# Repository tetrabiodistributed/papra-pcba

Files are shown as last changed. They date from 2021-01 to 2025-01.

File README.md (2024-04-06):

# PAPRA Printed Circuit Board Assembly (PCBA)

Full documentation page for building the PAPRa can be found here: https://tetrabiodistributed.github.io/papra/

Firmware for flashing the PAPRA PCBA can be found here: https://github.com/tetrabiodistributed/papra-pcb-firmware/tree/main/papracode

## Notes for programming

* Make a UPDI Programmer: https://create.arduino.cc/projecthub/john-bradnam/create-your-own-updi-programmer-1e55f1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
* The board features a UPDI header on the top left of the PCB (top being the side with the battery connectors) the pins are top to bottom 5V, GND and data. 
* Setup Arduino: https://www.hackster.io/john-bradnam/using-the-new-attiny-processors-with-arduino-ide-612185
* You will need to use the megaTinyCore library by SpenceKonde: https://github.com/SpenceKonde/megaTinyCore

Upload settings can be found in the arduino program. 

Please note that there are a number of ATTiny SKUs that are compatible with this PCB and code, please refer to the below table when choosing an appropriate IC.

| Model number | Confirmed | Notes |
| --- | --- | --- |
| ATtiny204SSN_, | Yes | See Below(1)  |
| ATtiny404SSN_, | Yes | 	 |
| ATtiny804SSN_, | Yes | |
| ATtiny1604SSN_,| Yes | 	 |
| ATtiny214SSN_, | Yes | See Below(1)  |
| ATtiny414SSN_, | Yes | 	 |
| ATtiny814SSN_, | Yes | |
| ATtiny1614SSN_,| Yes | 	 |
| ATtiny1624SSU, | Yes | 	 |

(1)ATtiny 204 and 214 have limited (2K) flash memory for program space, but the firmware can be made to fit by sacraficing the bootup LED sequence.

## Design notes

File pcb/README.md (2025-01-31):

The Tetra PAPRA project requires 1 PCBA, v.7 or newer.

PaprControlPCB - this is a speed controller that allows for adjusting speed of blower

Note:
A PCB is a bare board.
A PCBA is an assembly of a PCB and OTS (off the shelf) components, which are typically a mix of surface mount and thru-hole components.

PCBA Bring-Up Instructions:

1. Connect power to the board via 2.5mm DC jack (H1) using 12V Nominal (7V min, 14V max) DC power, ideally current limitable. Do not connect fan to the output connector at this time.



* Note DC polarity on connector is important, center pin is positive.
   * Insertion length on connector is 8.4mm, so body of mating jack should be at least this length.
   * For use with a bench power supply, a cut-end cable option is [Tensility CA-2185](https://www.digikey.com/en/products/detail/tensility-international-corp/CA-2185/568576) 
   * For a standalone power adapter, consider a [Tri-Mag L6R06H-120 12V/6W supply](https://www.digikey.com/en/products/detail/tri-mag-llc/L6R06H-120/7682617)
2. For adjustable power supply, set the voltage to12V and set initial current limit to ~25mA, which should be sufficient to power up processor and drive LEDs.
3. Turn the potentiometer/switch (POT1) to ON. 



4. Confirm the power LED (LED5) illuminates with 12V power.



5. Measure 5V regulator (U1) is outputting 5VDC. This can be inspected with a voltmeter measuring the UDPI header as follows:
   * Pin 2 is GND
   * Pin 3 is +5V
6. At this point, the board is powered and ready for programming via UPDI. Follow the instructions [here.](https://github.com/tetrabiodistributed/PAPRA-PCB/blob/main/README.md).
7. Upon successful completion of firmware installation, confirm the board powers up and the 4 LEDs (LED1 - LED4) light up at boot up in a sequence.
8. For boards with the buzzer installed, confirm the buzzer chirps at bootup.
9. In preparation for testing with a DC blower and battery, disconnect the DC jack from H1.
10. Source a fully charged [Milwaukee M12 Red Lithium Battery 48-11-2401](https://www.milwaukeetool.com/Products/Batteries-and-Chargers/M12-Batteries-and-Chargers/48-11-2401) or similar. 
11. Connect DC power to BNC connector (H2).
* WARNING: If the board is not installed in the battery housing, pay careful attention to the polarity
12. Turn on potentiometer (POT1) and adjust the fan speed from high to low, which checking the DC blower is working and speed is changing with potentiometer adjustments.

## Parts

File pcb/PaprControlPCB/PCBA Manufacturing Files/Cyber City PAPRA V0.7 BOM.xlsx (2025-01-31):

 | Client Name | Patrick Campbell |  |  | The better this is filled out, the easier our job is and we appreciate the help.
 | Company Name | Tetra Bio Distributed
 | Phone Number
 | Email Address | patrick.campbell@tetrab.io |  |  | Please complete Columns B, C, D, E, F and G. Additional notes always help us do a better job.
 | Board Name | PAPRA V0.7
 | Assembly Quantity | 25
Line | Description | Designators | Package | Qty | Manufacturer | MPN | Notes | Substitute | Customer Provided? | Vendor | Vendor PN | Vendor PPU
1 | Solder Tab Terminal; Uninsulated; Tin over Nickel Plated; Right Angle; 6.35x0.83mm | BATT+ BATT- | THT | 2 | TE Connectivity | 1217754-1 |  |  |  | DigiKey | A112005-ND | 0.2314 | 2 | TE Connectivity | 1217754-1
2 | Multilayer Ceramic Capacitor, 1 uF, 50 V, Â± 10%, X7R, 0805 [2012 Metric] | C1 C3 C8 C11 | C0805 | 4 | Samsung | CL21B105KBFNNNG |  |  |  | DigiKey | 1276-6470-1-ND | 0.0373 | 4 | Samsung | CL21B105KBFNNNG
3 | Multilayer Ceramic Capacitor, 0.1 uF, 50 V, Â± 10%, X7R, 0805 [2012 Metric] | C2 C9 C10 | C0805 | 3 | Samsung | CL21B104KBCNFNC |  |  |  | DigiKey | 1276-2444-1-ND | 0.0206 | 3 | Samsung | CL21B104KBCNFNC
4 | Cap Tant Solid 10uF 16V A CASE 10%( 3.2 X 1.6 X 1.6mm) Inward L SMD 3216-18 3 Ohm 125C T/R | C4 | A/3216-18R | 1 | KYOCERA AVX | TAJA106K016RNJ |  |  |  | DigiKey | 478-1655-1-ND | 0.1878 | 1 | KYOCERA AVX | TAJA106K016RNJ
5 | Multilayer Ceramic Capacitor, 3600 pF, 50 V, Â± 5%, C0G (NP0), 0805 [2012 Metric] | C5 | C0805 | 1 | Murata | GRM2165C1H362JA01D |  |  |  | DigiKey | 490-3318-1-ND | 0.069 | 1 | Murata | GRM2165C1H362JA01D
6 | Multilayer Ceramic Capacitor, 2700 pF, 50 V, Â± 5%, C0G (NP0), 0805 [2012 Metric] | C6 | C0805 | 1 | TDK | C2012C0G1H272J060AA |  |  |  | DigiKey | 445-7508-1-ND | 0.0768 | 1 | TDK | C2012C0G1H272J060AA
7 | Multilayer Ceramic Capacitor, 10 uF, 16 V, Â± 10%, X5R, 0805 [2012 Metric] | C7 | C0805 | 1 | Samsung | CL21A106KOQNNNG |  |  |  | DigiKey | 1276-6455-1-ND | 0.0404 | 1 | Samsung | CL21A106KOQNNNG
8 | ALU Electrolytic; SMD; EDT; +125Â°C; 25VDC; 10ÂµF; 10 x 10.2 | C12 | PANASONIC_F | 1 | KEMET | EDT227M025S9PAA |  |  |  | DigiKey | 399-20523-1-ND | 0.5946 | 1 | KEMET | EDT227M025S9PAA
9 | Diode Schottky Barrier 100V 1A 2-Pin SOD-123FL T/R | D1 D2 | SODFL3718X115 | 2 | ROHM | RB168MM100TR |  |  |  | DigiKey | RB168MM100CT-ND | 0.2274 | 2 | ROHM | RB168MM100TR
10 | 2.0 x 5.7 mm, 5.0 A, Horizontal, Panel Mount, Dc Power Jack Connector | H1 | THT | 1 | CUI Devices | PJ-066A |  |  |  | DigiKey | CP-066A-ND | 2.3224 | 1 | CUI Devices | PJ-066A
11 | Conn BNC RCP 0Hz to 4GHz 50Ohm Solder RA Thru-Hole Gold Tube | H2 | THT | 1 | TE Connectivity | 5226990-3 |  |  |  | DigiKey | A32254-ND | 3.5854 | 1 | TE Connectivity | 5226990-3
12 | 2.0X1.2MM Red SMD 0805 Led | LED1 LED2 LED3 LED4 LED5 | CHIPLED_0805 | 5 | SunLED | XZMDK54W-4 |  |  |  | DigiKey | 1497-XZMDK54W-4CT-ND | 0.1118 | 5 | SunLED | XZMDK54W-4
13 | Res Conductive Plastic POT 10K Ohm 20% 1/20W 1(Mech)Turn 6mm Pin Panel Mount/Through Hole | POT1 | THT | 1 | BI Technologies | P091S-FC20BR10K |  |  |  | DigiKey | 987-1283-ND | 1.818 | 1 | BI Technologies | P091S-FC20BR10K
14 | N-Channel 20 V 90 mOhm Surface Mount Enhancement Mode Mosfet -SOT-23-3 | Q1 Q2 | SOT23 | 2 | Diodes Inc. | DMG2302U-7 |  |  |  | DigiKey | DMG2302U-7DICT-ND | 0.2117 | 2 | Diodes Inc. | DMG2302U-7
15 | Res Thick Film 0805 10K Ohm 1% 0.125W Â±100ppm/Â°C Molded SMD Paper T/R | R1 R9 R11 R12 R20 | R0805 | 5 | Stackpole Electronics | RMCF0805FT10K0 |  |  |  | DigiKey | RMCF0805FT10K0CT-ND | 0.0102 | 5 | Stackpole Electronics | RMCF0805FT10K0
16 | Res Thick Film 0805 18K Ohm 1% 1/8W Â±100ppm/Â°C Molded SMD SMD Paper T/R | R2 | R0805 | 1 | Stackpole Electronics | RMCF0805FT18K0 |  |  |  | DigiKey | RMCF0805FT18K0CT-ND | 0.025 | 1 | Stackpole Electronics | RMCF0805FT18K0
17 | Res Thick Film 0805 120 Ohm 1% 1/8W Â±100ppm/Â°C Molded SMD SMD Paper T/R | R4 R5 R6 R7 R8 R13 | R0805 | 6 | Yageo | RC0805FR-13120RL |  |  |  | DigiKey | 13-RC0805FR-13120RLCT-ND | 0.0133 | 6 | Yageo | RC0805FR-13120RL
18 | Res Thick Film 0805 1.2K Ohm 1% 0.125W Â±100ppm/Â°C Molded SMD Paper T/R | R10 | R0805 | 1 | Stackpole Electronics | RMCF0805FT1K20 |  |  |  | DigiKey | RMCF0805FT1K20CT-ND | 0.025 | 1 | Stackpole Electronics | RMCF0805FT1K20
19 | Res Thick Film 0805 470K Ohm 1% 0.125W(1/8W) +/-100ppm/ÃŸC Epoxy SMD T/R | R14 | R0805 | 1 | Yageo | RC0805FR-07470KL |  |  |  | DigiKey | 311-470KCRCT-ND | 0.0340 | 1 | Yageo | RC0805FR-07470KL
20 | Res Thick Film 0805 75K Ohm 1% 0.125W Â±100ppm/Â°C Molded SMD Paper T/R | R15 | R0805 | 1 | Stackpole Electronics | RMCF0805FT75K0 |  |  |  | DigiKey | RMCF0805FT75K0CT-ND | 0.025 | 1 | Stackpole Electronics | RMCF0805FT75K0
21 | Res Thick Film 0805 390K Ohm 1% 1/8W Â±100ppm/Â°C Molded SMD SMD Paper T/R | R16 | R0805 | 1 | Stackpole Electronics | RMCF0805FT390K |  |  |  | DigiKey | RMCF0805FT390KCT-ND | 0.025 | 1 | Stackpole Electronics | RMCF0805FT390K
22 | Res Thick Film 0805 1K Ohm 1% 0.125W(1/8W) Â±100ppm/C Pad SMD Automotive T/R | R17 | R0805 | 1 | Stackpole Electronics | RMCF0805FT1K00 |  |  |  | DigiKey | RMCF0805FT1K00CT-ND | 0.025 | 1 | Stackpole Electronics | RMCF0805FT1K00
23 | Res Thick Film 0805 360K Ohm 1% 1/8W Â±100ppm/Â°C Molded SMD SMD Paper T/R | R18 | R0805 | 1 | Stackpole Electronics | RMCF0805FT360K |  |  |  | DigiKey | RMCF0805FT360KCT-ND | 0.025 | 1 | Stackpole Electronics | RMCF0805FT360K
24 | Res Thick Film 0805 56K Ohm 1% 1/8W Â±100ppm/Â°C Molded SMD SMD Paper T/R | R19 | R0805 | 1 | Stackpole Electronics | RMCF0805FT56K0 |  |  |  | DigiKey | RMCF0805FT56K0CT-ND | 0.025 | 1 | Stackpole Electronics | RMCF0805FT56K0
25 | 12 mm, 12 Vdc, 85 dB, Through Hole, Driving Circuit, Magnetic Audio Indicator Buzzer | SG1 | F/TMB | 1 | CUI Devices | CMI-1295-1285T |  |  |  | DigiKey | 102-CMI-1295-1285T-ND | 0.858 | 1 | CUI Devices | CMI-1295-1285T
26 | 150-mA 16-V low-dropout (LDO) voltage regulator with high-accuracy 5-SOT-23 -40 to 125 | U1 | SOT25 | 1 | Texas Instruments | LP2985A-50DBVR |  |  |  | DigiKey | 296-26128-1-ND | 0.538 | 1 | Texas Instruments | LP2985A-50DBVR
27 | AVR series Microcontroller IC 8-Bit 20MHz 16KB (16K x 8) FLASH 14-SOIC | U2 | SOIC14 | 1 | Microchip | ATTINY1624-SSU |  |  |  | DigiKey | 150-ATTINY1624-SSU-ND | 0.9316 | 1 | Microchip | ATTINY1624-SSU
28 | 2.7-V to 23-V, 28-mâ„¦, 5.5-A eFuse with integrated reverse polarity protection 10-VQFN-HR -40 to 125 | U9 | 10-VQFN-HR | 1 | Texas Instruments | TPS259472ARPWR |  |  |  | DigiKey | 296-TPS259472ARPWRCT-ND | 1.3356 | 1 | Texas Instruments | TPS259472ARPWR
29 |  |  | N/A |  |  |  |  |  |  |  |  |  | 1 | Dialight | 515-1020F
30 |  |  | N/A
31 |  |  | N/A
32 |  |  | N/A
33 |  |  | N/A
34 |  |  | N/A
35 |  |  | N/A
36 |  |  | N/A
37 |  |  | N/A
38 |  |  | N/A
39 |  |  | N/A
40 |  |  | N/A
41 |  |  | N/A
42 |  |  | N/A
43 |  |  | N/A
44 |  |  | N/A
45 |  |  | N/A
46 |  |  | N/A
47 |  |  | N/A
48 |  |  | N/A
49 |  |  | N/A
50 |  |  | N/A
51 |  |  | N/A
52 |  |  | N/A
53 |  |  | N/A
54 |  |  | N/A
55 |  |  | N/A
56 |  |  | N/A
57 |  |  | N/A
58 |  |  | N/A
59 |  |  | N/A
60 |  |  | N/A
61 |  |  | N/A
62 |  |  | N/A
63 |  |  | N/A
64 |  |  | N/A
65 |  |  | N/A
66 |  |  | N/A
67 |  |  | N/A
68 |  |  | N/A
69 |  |  | N/A
70 |  |  | N/A
71 |  |  | N/A
72 |  |  | N/A
73 |  |  | N/A
74 |  |  | N/A
75 |  |  | N/A
76 |  |  | N/A
77 |  |  | N/A
78 |  |  | N/A
79 |  |  | N/A
80 |  |  | N/A
81 |  |  | N/A
82 |  |  | N/A
83 |  |  | N/A
84 |  |  | N/A
85 |  |  | N/A
86 |  |  | N/A
87 |  |  | N/A
88 |  |  | N/A
89 |  |  | N/A
90 |  |  | N/A
91 |  |  | N/A
92 |  |  | N/A
93 |  |  | N/A
94 |  |  | N/A
95 |  |  | N/A
96 |  |  | N/A
97 |  |  | N/A
98 |  |  | N/A
99 |  |  | N/A
100 |  |  | N/A

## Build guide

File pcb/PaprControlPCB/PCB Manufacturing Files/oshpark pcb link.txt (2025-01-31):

https://oshpark.com/shared_projects/L2hfni0D

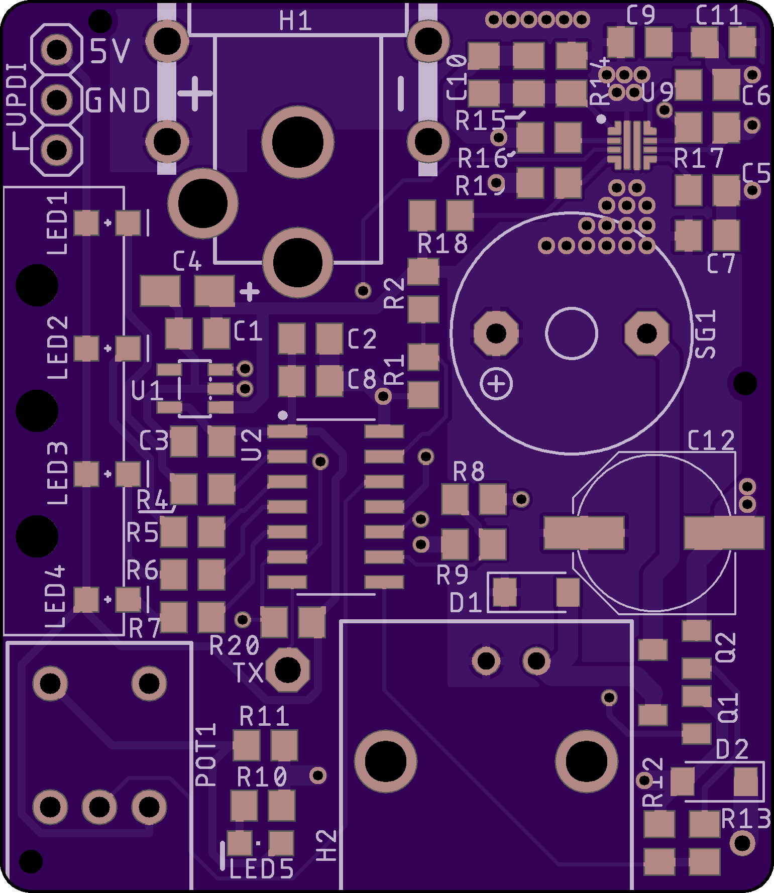
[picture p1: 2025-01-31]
pcb/PaprControlPCB/PCB Manufacturing Files/top.PNG

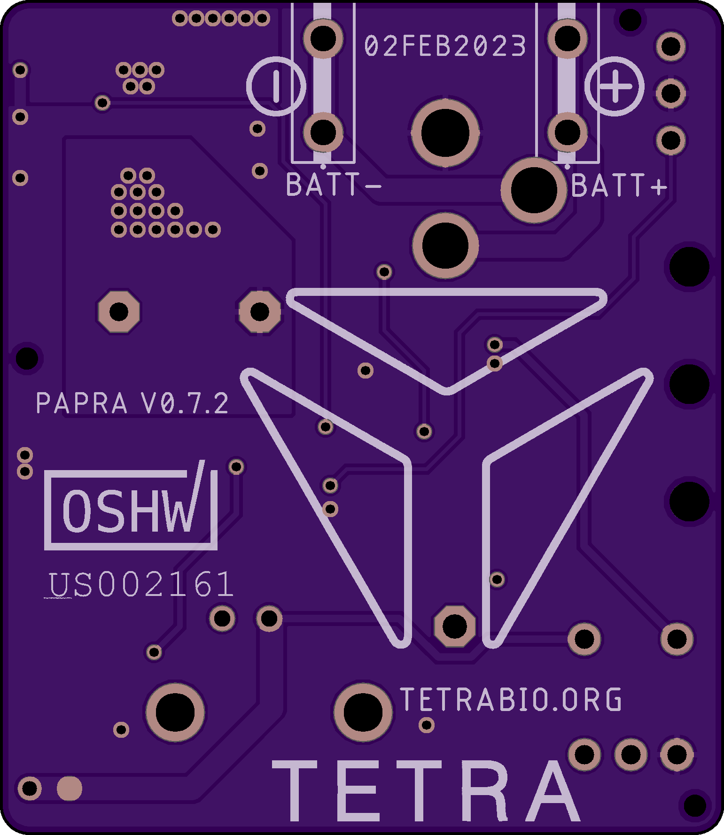
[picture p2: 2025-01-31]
pcb/PaprControlPCB/PCB Manufacturing Files/bottom.png

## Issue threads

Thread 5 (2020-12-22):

Battery Level Indicator Check

DHHwangPhD, 2020-12-22:
With 3500 mA/hr battery,
Last light to flashing light = 1h 15mins
Flashing light to shut down = 13 mins

mechatroniks-git, 2021-02-04:
Battery LEDs are close, but don't exactly align with the Milwaukee M12 LEDs (these are 4 LEDs on the DC charger that readout battery life). A compete measurement needs to happen over 4+ hours while constantly checking the battery readout on the M12 charger by pressing a button on the charger. Simultaneously, need to read serial stream from the board to get battery ADC readings at the moment the M12 LED readout changes.

mmroden, 2021-02-13:
This is a nice to have, not critical

mmroden, 2022-05-05:
This is done

Closed 2022-05-05.

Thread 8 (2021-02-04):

PWM output pin chosen has configuration limitations

mechatroniks-git, 2021-02-04:
WO3 is currently used, ideally it should be WO0 - WO2 to avoid using TCA0 in split-mode.  See: https://github.com/SpenceKonde/megaTinyCore/blob/master/megaavr/extras/TakingOverTCA0.md

darraghbr, 2021-02-04:
Is it worth testing this with a bodge wire to see if the proposed changes have the desired impact?

Closed 2021-02-08.

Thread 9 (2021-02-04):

Reverse voltage to potentiometer

mechatroniks-git, 2021-02-04:
0 & 5V should be swapped on potentiometer to eliminate the need to invert the scale in code.

darraghbr, 2021-02-06:
Can we generate a related issue for the changes to be made in the firmware?

Closed 2021-02-08.

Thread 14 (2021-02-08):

Buzzer when battery is about to run out

mmroden, 2021-02-08:
Feature request: when the battery is low, an audible signal as well as the gauge would be helpful

mmroden, 2021-02-13:
version 0.4 at the earliest

mechatroniks-git, 2021-04-23:
Will add this buzzer to v0.5
12V Buzzer - https://lcsc.com/product-detail/Buzzers_Fengming-YS-MBZ12095DYB12_C409840.html/?href=jlc-SMT
[datasheet](https://datasheet.lcsc.com/szlcsc/1912171631_Fengming-YS-MBZ12095DYB12_C409840.pdf)

mechatroniks-git, 2021-05-01:
Buzzer sourced locally: https://www.jameco.com/z/CEM-1212C-CUI-Electromagnetic-Audio-Buzzer-12V-35mA-85dB-2-3kHz_2286415.html
 https://www.jameco.com/Jameco/Products/ProdDS/2286415.pdf

mmroden, 2021-05-22:
closed by #49

mechatroniks-git, 2021-07-21:
Digikey Buzzer: https://www.digikey.com/en/products/detail/intervox/BRT1209P-12-C/13693933

Closed 2021-06-01.

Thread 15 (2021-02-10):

Papra PCB engineering drawing

mmroden, 2021-02-10:
Please submit an engineering diagram in PDF, PNG, whatever makes sense.

Bonus points for a soldering jig.

darraghbr, 2021-02-10:
[A-TET- Papra Control PCBA Drawing.pdf](https://github.com/tetrabiodistributed/PAPRA-PCB/files/5961311/A-TET-.Papra.Control.PCBA.Drawing.pdf)

@mechatroniks-git Please review when able.

mechatroniks-git, 2021-02-11:
Looks nice. A few comments:
1. The board, as it comes from JLC should have the fuse installed, no need to point that out.
2. The PCB should have a balloon
3. Washers & Nuts included with the potentiometer and DC jacks - not sure if they should be separate line items?
4. Lightpipe is already on the M12 controller BOM? It should only be on 1 BOM, probably the other one, as it needs to be assembled with the board, after the board is installed.

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

darraghbr, 2021-02-11:
Please see attached, I believe I have dealt with all of your comments.

Aside from the nuts and washers appearing on the BOM, Because they are seperate components there isn't a nice way to not have them visible on the BOM and also have them visible on the drawing. I can remove them from the drawing and BOM if desired.

[D-TET-.Papra.PCBA.Drawing.pdf](https://github.com/tetrabiodistributed/PAPRA-PCB/files/5968976/D-TET-.Papra.PCBA.Drawing.pdf)

mechatroniks-git, 2021-02-11:
LGTM

darraghbr, 2021-02-12:
@mmroden please review when able.

mmroden, 2021-02-12:
Man, this is _phenomenal_!

Closed 2021-02-12.

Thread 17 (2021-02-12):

Papra fan box PCB engineering drawing

darraghbr, 2021-02-12:
Submit an engineering diagram for the Papra fan box PCB in PDF

darraghbr, 2021-02-12:
First draft for review by @mechatroniks-git

[D-TET-001101-0 PapraFanBoxPCBA Drawing.pdf](https://github.com/tetrabiodistributed/PAPRA-PCB/files/5971070/D-TET-001101-0.PapraFanBoxPCBA.Drawing.pdf)

mmroden, 2021-02-13:
Version 0, not with the new airtight connectors

mechatroniks-git, 2021-02-15:
This version looks good.

The sealed connector PCB, v0.3 has been committed, ready for review

darraghbr, 2021-02-20:
Updated for new DC jack and general tidy up.

[D-TET-001101-0 Papra Fan Box PCBA Drawing.pdf](https://github.com/tetrabiodistributed/PAPRA-PCB/files/6016248/D-TET-001101-0.Papra.Fan.Box.PCBA.Drawing.pdf)

mechatroniks-git, 2021-02-20:
Looks good, but maybe something moved in assembly?
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

darraghbr, 2021-02-20:
The previous version of the drawing also showed a gap between the components and the board? If you want me to fix it I will.

mmroden, 2021-02-22:
Closed per discussion, work has been completed as there is a drawing for the papra pcba

Closed 2021-02-22.

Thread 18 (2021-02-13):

Airtight connector for the fan power board

mmroden, 2021-02-13:
The fan power board leaks air around the edges; this air leak seems to be keeping the system from passing N99.

mechatroniks-git, 2021-02-20:
merged, closing issue

Closed 2021-02-20.

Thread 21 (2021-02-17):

Resolve the exact model of fan

darraghbr, 2021-02-17:
After chatting with Darryl it seems there is a mismatch between the fans that are specced and the standard fans that are the same form factor.

With some napkin mathematics I do not believe that the fan that has been specced (from amazon) is delivering the flow rates and pressures that are quoted, as ultimately it is drawing the same wattage but is somehow delivering significantly higher performance than other standard fans.

darraghbr, 2021-02-18:
If we purchase a standard model like this one:

https://www.digikey.co.uk/product-detail/en/nmb-technologies-corporation/BG1203-B055-000-00/P12911-ND/740268

Then do some comparative tests between the fan acquired from amazon.

mmroden, 2021-02-22:
Testing involves a multimeter to measure current draw, to make sure that they blow the same amount of air.  Checking to see if the flow is about the same (for some given value of "the same")

darraghbr, 2021-02-22:
Updated my comment with the correct model of fan.

mechatroniks-git, 2021-04-23:
Tested the following blowers:
- [NMB BG1203-B045-00S-00](https://www.digikey.com/en/products/detail/nmb-technologies-corporation/BG1203-B045-00S-00/857938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)
- [Sunon PMB1212PLB2-A.(2).GN](https://www.digikey.com/en/products/detail/sunon-fans/PMB1212PLB2-A-2-GN/1021212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)

mmroden, 2021-04-24:
We will go with Sunon.  This will increase the BOM by $10 per individual part to $25/fan.  The amazon one can be recommended as an alternate source item for lower cost.

Closed 2021-04-24.

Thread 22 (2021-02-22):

Close the gap uncovered in the engineering drawing submitted for #17

mmroden, 2021-02-22:
There is a gap on the fan box PCB that needs to be closed

mmroden, 2021-02-22:
This was found in issue #17

mechatroniks-git, 2021-02-22:
Parts aligned and updated rigid group in Fusion.
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

Closed 2021-02-22.

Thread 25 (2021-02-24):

What ATTiny ICs are compatible

darraghbr, 2021-02-24:
There are dozens of different ATTiny ICs out there, we have specified the 1604 on the PCB, is that the minimum required? Are there any other SKUs that are compatible?

darraghbr, 2021-02-24:
So in theory any of these should work as long as the program takes less than 2 KiB of flash storage, 128 bytes of RAM and 64 bytes of EEPROM. Is there any way we can verify this?

ATtiny204, ATtiny404, ATtiny804, ATtiny1604
ATtiny214, ATtiny414, ATtiny814, ATtiny1614

mechatroniks-git, 2021-02-24:
I would say that any ATtiny__4SSN/ATtiny__4SSNR would work.
- 4SS is 14 pin SOIC device
- N is temp range with 20MHz. We could do the F, and get to 16MHz, but would have to adjust firmware for clock change (baud rate, pwm rate, blink rate, etc)
- R is just a packaging type for manufacturing (R for tape & reel), blank for tube or tray

The 0 series ATtiny_04, I've tested 204, 404 and 1604. This series is more than capable for this application and is lowest cost.
- 204 has limited flash, would require serial debug to be disabled and may not have room for future updates, but can be supported for now. May not support any future features (for example, we activate the expansion header for RF integration).
- The 404 is recommended for price vs current and future capabilities.
- The 804 should drop in without any concern.
- The 1604 tested and works, only installed it due to JLC availability (only chip they had at the time of order)

The 1 series ATtiny_14 chips have more SRAM and more hardware IO, but pin mapping is unchanged and should be compatible. The extra cost is not justified for this application, at this time. Code compiles for these devices without error, but should be tested if needed for compatibility confirmation.

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

mechatroniks-git, 2021-02-24:
Appnote on migration from 0 Series to 1 Series:
http://ww1.microchip.com/downloads/en/AppNotes/Microchip%20AN2636%20Migration%20Between%20tinyAVR%201-Series%20and%20tinyAVR%200-Series%2000002636A.pdf

confirms migration from 0 to 1 without any code changes
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

darraghbr, 2021-02-24:
Great work Patrick, I've noticed on JLC at the moment they have had some shortages of various ATTiny ICs and we have had to go with the 1614 on the boards for 3DCrowd. Perhaps some point down the line a list of compatible SKUs kept somewhere in the docs?

mechatroniks-git, 2021-02-24:
We can say the following are compatible:
*ATtiny204, *ATtiny404, ATtiny804, *ATtiny1604
ATtiny214, ATtiny414, ATtiny814, ATtiny1614
Ones with * being tested/confirmed

mechatroniks-git, 2021-02-24:
Code already has the following comment
```
  PCB is compatible with the following 14SOIC ATtiny chips: 404/804/1604 and 414/814/1614 should work (needs testing)
  Attiny204 - this could work without serial output and some code optimization
```
I'll add the SSN clarification on next commit

Closed 2021-02-24.

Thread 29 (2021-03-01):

BOM scrub

mmroden, 2021-03-01:
Need to check to make sure that the BOM is updated, and order necessary parts.

Order fans through digikey

mechatroniks-git, 2021-03-05:
I built a DigiKey Cart for the PAPR components I need. See https://www.digikey.com/short/r80dwtpq

@DHHwangPhD Can you add in the blowers you wish to test?

mmroden, 2021-03-05:
requires amazon blower as well as the digikey fan so that we can compare

mechatroniks-git, 2021-03-06:
I added a couple of blower candidates to the cart using a dart board and blind fold selection process.
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

mechatroniks-git, 2021-03-08:
New cart: https://www.digikey.com/short/2jnh3hmq

darraghbr, 2021-03-08:
That NMB SKU is a PWM 3 wire fan, I assume you don't want that?

mechatroniks-git, 2021-03-08:
Final Cart https://www.digikey.com/short/wd4tffcn

mechatroniks-git, 2021-03-08:
And will need 1 of these for crimping: https://www.amazon.com/IWISS-Terminal-Crimping-SN-01BM-0-08-0-5mm/dp/B019ARWWFY

Closed 2021-03-08.

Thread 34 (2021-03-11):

waterproof/splashproof the papra?  How to do that?

mmroden, 2021-03-11:

darraghbr, 2021-03-12:
We could use a set of louvres on the fan box to hopefully keep the worst of any rain etc off the filter pack.

It may limit which orientation you can mount the fan box.

darraghbr, 2021-03-12:
For the M12 controlled we could use a 3D printed TPU or other flexible gasket that seals between the battery and the M12 housing. The lid could then be attached permanently with a waterproof adhesive and IP rated potentiometers and DC jacks utilised.

darraghbr, 2021-03-12:
An example of the louvers is something like what are used on armoured fighting vehicles to protect the radiators and air intakes.

They are also used on dirt bikes to protect the radiator from debris.

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

mmroden, 2021-03-20:
Handled by #37 and #38 in this project

mmroden, 2021-08-11:
redundant to #55 and work done in the papr-print-files

Closed 2021-08-11.

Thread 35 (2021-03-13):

IP Rated dc jack requires specific compatible cable connector

mechatroniks-git, 2021-03-13:

mmroden, 2021-03-20:
BNC connectors obviate this problem

Closed 2021-03-20.

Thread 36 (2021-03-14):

Bad fan boards can cook the m12 controller boards

mechatroniks-git, 2021-03-14:
When testing a "bad" fan board, multiple m12 v2 controller boards and a Milwaukee m12 charger were all rendered nonfunctional once power was applied to the system when testing a fan.

mmroden, 2021-03-20:
Should be solved by the 0.3 board

mmroden, 2021-03-29:
Now will be solved by not having a fan board

mechatroniks-git, 2021-03-29:
Possible bad wiring in fan box (dead short on fan power wiring or in fan itself) can cause same issue. PCB V3+ should protect.

mechatroniks-git, 2021-04-17:
Added 1A fuse on 12V to DC blower, tested with dead short on fan output, board survived and is fully functional once short is removed.  Recommend adding 2nd fuse to DC blower on v.5 PCB, so board should have 2 fuses in parallel, one for DC blower, one for everything else.

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

mechatroniks-git, 2021-04-17:
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

mmroden, 2021-05-13:
Closed by #43

mmroden, 2021-05-22:
closed by #49

Closed 2021-06-01.

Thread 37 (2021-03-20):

Update M12 board with BNC connector

mmroden, 2021-03-20:

mechatroniks-git, 2021-03-20:
This is a decent, low cost BNC. If nobody objects, I'll design it in.
https://octopart.com/5227161-9-te+connectivity-39536535?r=sp
https://www.te.com/usa-en/product-5227161-9.html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

Closed 2021-05-16.

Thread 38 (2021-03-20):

Investigate removing fan box board with BNC connector

mmroden, 2021-03-20:

mmroden, 2021-03-29:
There will no longer be a fan box board

Closed 2021-05-16.

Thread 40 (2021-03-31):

Investigate 0.2 papra board failure

mmroden, 2021-03-31:
Something failed in Patrick's PAPR, need to understand why

mechatroniks-git, 2021-04-03:
ATtiny failed

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

mechatroniks-git, 2021-04-11:
Replacing ATtiny solved issue, not sure what caused it

mechatroniks-git, 2021-04-17:
Replaced with ATtiny1624 (2-Series) chip and programmed with Megatinycore v2.3.1 using this code: https://github.com/tetrabiodistributed/PAPRA-PCB/blob/c38be3ee90f81fe9fc7fcec78938d70674fdf67d/firmware/papracode/papracode.ino. Board is fully functional, will keep testing.

mechatroniks-git, 2021-04-23:
Failure likely caused by GND-SENSE input to microcontroller

mmroden, 2021-05-22:
fixed by version 0.4, #43

Closed 2021-05-22.

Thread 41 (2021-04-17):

Investigate blown rev .2 PCB

mechatroniks-git, 2021-04-17:
At the end of the 4/10/22 build party, tested new IP rated DC cable, which had short, fried Mark's M12 control board.

mechatroniks-git, 2021-04-17:
Powered up m12 board, found 5V regulator was hot and only outputting 1.4 VDC.

mechatroniks-git, 2021-04-17:
MOSFET also blown. Replaced, board is now working. Same failure mode, shorted output can fry the MOSFET and ATTINY. Will be resolved in V.5 of PCB, for now, don't short the output and you will be good.

ATtiny was replaced with 214, but 2K code space fills up, so had to remove startup knight-rider LED sequence to fit. Same issue likely with the 204 flavor. Also, v2.3.1 of the MegaTinyCore has a bug with this chip, created issue. V2.9 works.

darraghbr, 2021-04-24:
It might be worth adding an eFuse IC? It would replace the polyfuse, and could provide overcurrent, overvoltage and short protection.

https://www.ti.com/power-management/power-switches/efuse-hotswap-controllers/overview.html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

mmroden, 2021-05-22:
closed by #43

Closed 2021-05-22.

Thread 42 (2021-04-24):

check that 0.5 rev boards fit in the May 2021 version of m12

mmroden, 2021-04-24:
The boards are getting a bit bigger and will have a buzzer, so check their size

mechatroniks-git, 2021-04-24:
We can grow the PCB up to ~6mm

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

Closed 2021-05-01.

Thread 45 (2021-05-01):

need to be able to see LEDs from other orientations

mmroden, 2021-05-01:
UX issue-- lights are visible only from one side

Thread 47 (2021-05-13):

test that protection circuitry actually protects

mmroden, 2021-05-13:
Going to also need to put that in the testing docs

mechatroniks-git, 2021-05-13:
Tested on .4 board by shorting the output to the fan, board survived several attempts

mechatroniks-git, 2021-05-16:
Tested v.5 PCB
1. Shorted BNC while adjusting the fan output
2. Applied reverse polarity to the battery terminals

In both cases, board suffered no damage and remained fully functional.

mmroden, 2021-05-22:
closed by #49

Closed 2021-06-01.

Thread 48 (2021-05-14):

Test megaTinyCore v2.3.2

darraghbr, 2021-05-14:
Looks like there is a new version of megaTinyCore, hopefully it resolves some of the timer issues @mechatroniks-git had with the now deprecated 2.3.1.

mechatroniks-git, 2021-05-15:
Yes, looks fixed. I compiled with 2.3.2 for 204, 814, 1614 and 1624, no more compile errors.

mmroden, 2021-05-15:
dependent on the buzzers arriving

mechatroniks-git, 2021-05-15:
2.3.2 works, compiled and downloaded to 1624 target.

mmroden, 2021-05-22:
tested by and works with 0.5 (#49)

Closed 2021-06-01.

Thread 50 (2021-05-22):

have the sensirion sensor report slm for papr testing purposes

mmroden, 2021-05-22:
need to use this vs the spirometer for these flows

mechatroniks-git, 2021-05-23:
see https://github.com/tetrabiodistributed/papra-pcb-firmware/pull/1

mmroden, 2021-06-30:
Firmware is done and spits out the slm^2 in #1 in papra-pcb-firmware

Closed 2021-06-30.

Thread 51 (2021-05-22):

Papra Testing

mmroden, 2021-05-22:
blocked on #50: once we have the sensirion hooked up, test the papra to see if we can reach 113 lpm:

sensirion testing:
hose: none, 3', 4', 6' (probably don't need 6 foot)
filter: in, not in
shield: on, not on
battery: potentiometer on high, low, bench power supply dialed in
diffuser piece: in, not in
horizontal vs vertical fan orientation
where does it need to be checked? outlet of the fan?
choose a spot to measure on the hose
don't have the host characterized, put it at the end of the hose
where it's measured isn't that important (according to Patrick)
straight hose before the sensor

mmroden, 2021-07-17:
Done, documented, we know we need to change our designs.

Closed 2021-07-17.

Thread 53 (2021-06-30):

Power delivery redesign

darraghbr, 2021-06-30:
Now we have identified a number of fans that can deliver the required airflow we can now develop our power delivery circuitry to support it.

One of the fans we have identified (CUI CBM-979533B-154) can deliver the 4 CFM target but only for about half of the battery life, once the battery voltage drops below ~11V the fan can no longer deliver the required flow rate, these tests can be found in https://github.com/tetrabiodistributed/papr-print-files/issues/150

Our other option is to use the bigger brother of that fan (CUI CBM-979533B-168) which can deliver the required airflow at all usable battery voltages.

There are multiple options ahead of us, including using a higher voltage battery or a boost converter circuit with the -154 fan.

However the percieved path of least resistance is to use the current battery system with the -168 fan and accept the loss of runtime (~2 1/2 hours as opposed to 3 1/2 hours)

We need to replace the polyfuse on the board to increase the current carrying capacity and potentially rethink the way we do the reverse polarity protection circuit.

A new version of the firmware will be required to better control the CUI fan.

The BNC connectors should be checked to ensure sufficient current carrying capacity.

mechatroniks-git, 2021-07-17:
The go-forward path would be:

- [ ] Replace 2A reverse polarity diode with this [circuit](https://hackaday.com/2011/12/06/reverse-voltage-protection-with-a-p-fet/)
- [ ] Change fuse to [3A](https://www.digikey.com/en/products/detail/littelfuse-inc/1206L300SLTHYR/3661962)

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

mechatroniks-git, 2021-07-18:
If we were to use an eFuse, which @darraghbr had brought up prior, one chip (with caps and resistors) could replace the fuse and reverse polarity mosfet circuit, while giving us reverse polarity, over-current, under and over voltage, and over-temp protection, all for ~$1.50, but not available at JLC.

https://www.digikey.com/en/products/detail/texas-instruments/TPS259472ARPWR/14124020

darraghbr, 2021-07-18:
I believe it can also provide a current monitor signal as well, bottom of page 38 on the datasheet. If there was a package we could easily hand solder I'd say go for it. What are your thoughts @mechatroniks-git ?

darraghbr, 2021-07-18:
It's also a really bizzare looking footprint. I wonder how they get away with such a tiny little GND pad.

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

mechatroniks-git, 2021-07-19:
Well @darraghbr, it solves all the design issues, but we complicates the assembly, as JLC won't have it. We would have to make them elsewhere, but It's worth a try.

Yea, the ground pin can be small as no current should be flowing to ground it under normal operation. It will go from IN to OUT. During fault, it should shut it all down.

darraghbr, 2021-07-19:
Ah ok, that makes sense, I was mainly thinking from a thermal point of view.

Alright do you want to edit the check boxes to add this in?

darraghbr, 2021-07-19:
I think we want to select from the bottom two models as they work as a circuit breaker rather than trying to limit the current? The only way we would get an over current is from a short somewhere?

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

mechatroniks-git, 2021-07-21:
Seeing that only 2 flavors of the chip are available:
- there are ~5000 of the TPS259472ARPWR - pin selectable overvoltage, currentl limit, auto-retry on fault (plus 10K at factory)
- there are 150 of the TPS259474LRPW - Circuit breaker, latch off

The decision will likely be the more available one.  Pads are the same, so I'll design in the chip.

The neat thing is we can use the active current limit to control the max power to the fan, if we wanted to keep it at a certain wattage, although we can do that in the micro by setting the max PWM duty cycle.

darraghbr, 2021-07-21:
Makes sense, I have had a first stab at the design calcs and I will send you the spreadsheet via DM.

mechatroniks-git, 2021-07-22:
Library Symbol vs Datasheet
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

mechatroniks-git, 2021-07-22:
Footprint

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

mechatroniks-git, 2021-07-22:
Schematic roughed in

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

DRC errors need to be cleaned up, it doesn't like the clearances.
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

mechatroniks-git, 2021-07-26:
Schematic for review attached. Still need to specify R & C values for E-Fuse.

[Papra v0.6 - preliminary for review.pdf](https://github.com/tetrabiodistributed/PAPRA-PCB/files/6879537/Papra.v0.6.-.preliminary.for.review.pdf)

darraghbr, 2021-07-26:
Page 59 of the data sheet:

"For all applications, a ceramic decoupling capacitor of 0.1 μF or greater is recommended between the IN
terminal and GND terminal."

I'll keep looking and update this comment with anything else I find.

mechatroniks-git, 2021-07-26:
Good catch, updated schematic:
[Papra v0.6 - preliminary for review 2.pdf](https://github.com/tetrabiodistributed/PAPRA-PCB/files/6881038/Papra.v0.6.-.preliminary.for.review.2.pdf)

darraghbr, 2021-07-26:
I've had a crack at using the spreadsheet to get some intial values, any ones I'm really not sure about have a question mark after them.

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

These are the main inputs that I have used, I don't know what the load capacitance is (not very much considering it should be mostly inductive?) or the load at startup so I left them both default.

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

mechatroniks-git, 2021-07-27:
The battery when discharging will tolerate 2.5V/cell x 3 cells = 7.5V per [datasheet](https://www.batteryspace.com/prod-specs/NCR18650B.pdf). In software, we shut down at 2.8V/cell = 8.4V. With the 3% tolerance, we should set the UVLO Set Point to 8.15V, instead of 9V.

We have 11uF worth of caps at the input to the voltage regulator (c1 + c4). Being that we turn on with delays in code to startup, that will be the only capacitance this will see.

C7 can be fairly low since we have a stiff supply (battery just a few mm away) and shouldn't see much voltage droop. We don't need 470uF, I'd leave it 1uF and rely on that 10uF tantalum to deliver.

darraghbr, 2021-07-27:
Alright makes sense, so the new values will be something like this then.

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

Only input I changed was the UVLO set point down to 8.15V. With the closest resistor that gives us a undervolt set point at 7.4V on the VIN falling (seems low)

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

Because we aren't so interested in the VIN Rising threshold does it make sense to bump R2 to 75K which would give us a VIN falling threshold of 7.99V

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

darraghbr, 2021-07-27:
Also holy vias batman.

mmroden, 2021-08-11:
Reopening because we haven't physically tested that the fix works

mmroden, 2021-08-14:
Boards are in hand, digikey on Monday, Stencils on Tuesday, lots of tiny soldering, so there's a risk that we can't get the fused circuitboard

mmroden, 2021-08-21:
Patrick has build 3 boards, visual inspection has fail, fail, maybe pass

mmroden, 2021-08-21:
Should eventually take to a build house, very difficult to do by hand.  $1k/run, but at least 100 boards per run, maybe up to 250 boards.

mmroden, 2021-08-21:
Looking like best case scenario now is 1 board that's passing visual inspection, other two are likely broken from overwork.  May require a microscope for further work.

darraghbr, 2021-08-21:
@mechatroniks-git What do you think the issue is? Is it getting that weird eFuse package soldered properly?

mechatroniks-git, 2021-08-21:
Mostly a manufacturing issue, due to inability to see solder blobs on the .35mm pitch QFN package. Shorts have been removed, but power up was not successful. Will debug more later.

darraghbr, 2021-08-21:
That's a shame, it would be nice to get one working just to prove that we can and to de-risk a larger batch that we can get a boardhouse to assemble. We could also park the eFuse board as a fork and then once we are happy with the boards work the eFuse back in for a larger production run.

mmroden, 2021-08-30:
dv/dt change (instantaneous voltage spike on powerup) is causing issues.

mmroden, 2021-08-30:
sorry during runtime.

mmroden, 2021-09-01:
Continued in issue #59

Closed 2021-09-01.

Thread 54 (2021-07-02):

LED's not flashing green

capsulecorplab, 2021-07-02:
This may be a non-issue, since it happened after using it to power a stepper motor driver for a NEMA17, but the LED arrays don't flash green when the control knob is turned back on and instead goes directly to red. The battery seems fine and I don't see any burnt IC's. Any thoughts?
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

mmroden, 2021-07-02:
Iirc the LEDs are all one color, not multiple colors for different states.  Feature request, maybe?
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

capsulecorplab, 2021-07-02:
@mmroden you're right, the LED color was red. but this issues is concerning the LED arrays that indicate the battery level that aren't coming on

mechatroniks-git, 2021-07-19:
@capsulecorplab - v.2 had a critical failure mode that was fixed later. Issue was if the output fan was shorted, the microcontroller would blow up.

If you connected a low impedance load (NEMA stepper motor) to the FAN output, this would likely cause the chip failure.

mmroden, 2021-08-14:
@mechatroniks-git will get @capsulecorplab a replacement

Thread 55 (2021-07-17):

coat the m12 board for water proofing

mmroden, 2021-07-17:
mask up board after it's built, spray with some spray can conformal coating.  Will require documentation, of course

mechatroniks-git, 2021-07-17:
Acrylic is easiest to apply, least toxic and makes for easy rework. It has decent moisture protection. Silicone would be a good step up.

This acrylic looks like a good option: https://www.digikey.com/en/products/detail/acl-staticide-inc/8690/10270032

Conformal coatings will be easily removable with MG8310A coating stripper. https://www.mgchemicals.com/downloads/tds/tds-8310a-l.pdf

Background reading: https://www.techspray.com/the-essential-guide-to-conformal-coating

darraghbr, 2021-07-17:
Could also fill the case with potting compound but this would make any maintenance down the line much more challenging.

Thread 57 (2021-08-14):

How-to repair burnt out microcontroller

capsulecorplab, 2021-08-14:
Write a how-to guide for repairing a burnt out microcontroller on the PAPRA-PCB

capsulecorplab, 2021-08-14:
Any ATtinyXY4 should work, where X = 4/8/16 and Y=0/1/2. Best part to use is ATtiny1614-SSN

capsulecorplab, 2021-08-14:
But for debugging, look at this: https://github.com/tetrabiodistributed/PAPRA-PCB/issues/41#issuecomment-821879576 and https://github.com/tetrabiodistributed/PAPRA-PCB/issues/40

capsulecorplab, 2021-08-14:
need to cut the GND-SENSE line to prevent it from happening again

capsulecorplab, 2021-08-14:
will need a UPDI programmer: https://github.com/SpenceKonde/AVR-Guidance/blob/master/UPDI/jtag2updi.md

capsulecorplab, 2021-08-14:
most of these issues will only apply to the .2 rev

mmroden, 2022-05-05:
OBE

Closed 2022-05-05.

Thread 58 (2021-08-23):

Investigate a potentiometer with set positions rather than a continuous adjustment

mmroden, 2021-08-23:
so we can be sure to hit 4 CFM on at least one setting

mechatroniks-git, 2022-06-12:
How many positions?

We could have 2 - just on & off.

We're currently using this part: [P091S-FC20BR](https://www.ttelectronics.com/products/categories/potentiometers/potentiometers/p082d/)

You can build a part number with 1, 11,21 or 41 detents and be a drop in replacement, but not seeing any part availability beyond a Non-Stocked Lead-Time 23 Weeks with a minimum order of 1820 pieces.

There are other parts that are similar, but would require a new PCB and possibly changes to the housing

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

Closed 2022-06-13.

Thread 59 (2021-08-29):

e-Fuse chip tripping at mid-range

mechatroniks-git, 2021-08-29:
eFuse is holding at max current (2.6A) with 100% duty cycle. In the mid range, duty cycle is under 100%, eFuse will trip, unsure why. Tried adding caps (1st was a 10uF tantalum, then a 50uF electrolytic). Both seemed to help, suspect dv/dt. Was testing with power supply, possible better outcome with a battery, but none were charged.

darraghbr, 2021-08-31:
Just to clarify did you add caps to the voltage input or in seies with Cdvdt?

darraghbr, 2021-08-31:
Page 26 of the data sheet here. It states the fastest slew rate can be achieved by leaving the dVdt pin floating, might be worth a try?

Might be worth trying to measure the load capacitance and inrush current (although I'm sure we discussed the load capacitance and agreed it would be negligible?)

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

mechatroniks-git, 2021-08-31:
@darraghbr - I added the caps between the 12V rail & ground, after the fuse.

We're powering up OK (most of the time), just during run time, when the blower is running at mid-range duty cycle, we're tripping, so my theory is the DV/DT is the cause. I'll remove that dv/dt cap and test later today. Thanks for looking that up.

mechatroniks-git, 2021-09-01:
I removed C5, still tripping. We're seeing lots of noise on the battery and fused output. These are images right above the trip point, at duty cycle of ~66% ON.

Not sure what the problem is, ringing or if it's the ringing in the OFF or ON, but more filtering will help. I need to study the datasheet further, but if DVDT is inrush limiting, we would benefit from having a big (470uF?) electrolytic cap after the fuse to prevent that droop.

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

mechatroniks-git, 2021-09-01:
Here's a better grab, ch 1 & 2 at same amplitude, 1/2V per division. The battery voltage (ch2) not moving much.

Concerns:

- When fet turns off, we get ringing and a back EMF spike. We have a flyback diode, but it may not be fast enough.

- The voltage drop across the fuse is substantial, big droop at turn on

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

mmroden, 2021-09-01:
What do the waveforms look like with the known-good board?  Are we sure these waveforms are indicative of the underlying problem?  (not saying they shouldn't be resolved, but more that we're fixing the right thing)

darraghbr, 2021-09-02:
What does the PG pin read during these events?

ultraapa, 2021-09-07:
I think I understand the problem better now that I'm reading this post. The decoupling caps are there for initial high dv/dt voltage spike situations. The flyback protects against reverse current by a collapsed magnetic field from low or no voltage situations. So I would not think the caps and flyback would resolve the problem as the problem is at run time when I would think the voltage spikes are not present and voltage is good I hope. The decoupling and flyback (should be mandatory) are good design practices in any event. That being said, on initial blush it sounds like there may be some kind of "runaway" situation where current is being driven higher and higher until it causes a trip situation at the fuse. . I wonder if the the chip (TPS25947???) providing the current to the fuse is overheating? I have some questions but I'll those for in person discussion. It would interesting; however, to know the status of pin PG as Darragh suggests.

mechatroniks-git, 2021-11-07:
Comparing the eval board to our schematic:

1. TVS Diode on power input
2. 1uF cap on power input
3. R1 & R3 = 1M & 124K, while board has 470K & 75K. This sets the undervoltage lockout threshold @ 10.87V. Ours is set to 9V to match the battery discharge curve.
4. 100pF cap in parallel with R3
5. PGTH R2 & R4 set to 1M & 124K, while board has 360K & 56K (PG = 9V)
6. 2 Output caps @ 10uF and 220uF, while board has only 1uF
7. Schottky diode on output for protection

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

mechatroniks-git, 2021-11-07:
DV/DT cap had been removed in prior testing, left it off.
Adding a 560uF 50V cap (what I have on hand) provided the fix.  Board seems to be working fine with this addition.

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

Here is output to the fan @ 50% duty cycle
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

mechatroniks-git, 2021-11-07:
Still need to test board for:

- Reverse polarity protection
- Undervoltage and overvoltage protection
- Test current monitoring with ILM (needed for CFM confirmation)

Recommended changes for V.7.
1. Add 220uF AL cap to output of fuse
2. Change C7 to 10uF
3. Add 100nF in parallel with R15
4. Add 1uF to input
5. Add schottky diode on the output

Closed 2022-06-02.

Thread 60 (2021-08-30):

refactor PAPRA-PCB repo as DOF-Component

capsulecorplab, 2021-08-30:
DOF is an open-source framework for documenting BOM's, assembly instructions, and supporting documentation for open-source hardware.
A [DOF-Component](https://mach30.github.io/#_component) would enable compos-ability within other DOF-Components, doubly-sourced BOM's, and documenting [component functions](https://mach30.github.io/dof/#_function).

e.g., [TRRS Wheel Speed Sensor Module](https://github.com/modelb-llc/trrs-wssm/).

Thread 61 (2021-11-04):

nail down the final blower selection

mmroden, 2021-11-04:
Are we targeting the CUI-154?  It's passing all of our CFM requirements, and if so, we need to make this call so that we can have the boards properly paired and the electronics worked out.

If we can't get consistent power to the 154, may have to change things.

battery discharge curve shows that we'll drop to 11-10 volts, which can cause fan/board issues.

Buck boosters?  costs efficiency, they are pretty lossy, pricey, and bulky (it's a whole circuit, not an individual component).

The decision would require characterizing the battery voltages as the battery discharges; lower than 11 volts and the fans will be below 4CFM at max output, so could be used as a way to determine the life of a single battery.

May also want to characterize Milwaulkee brand batteries vs the amazon batteries.  Could break apart the Milwaulkee battery to see what battery cells it has.

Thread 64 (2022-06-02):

Create guide for flashing board with versions of firmware per fan

mmroden, 2022-06-02:
Need a guide for someone to flash versions of firmware to particular boards

mmroden, 2022-06-02:
The task: I have a board (rev 0.7), I have a fan from a given list, I'm going to build a fan box, what version of firmware do I need, how do I get it on the board, and how do I validate that I'm all good

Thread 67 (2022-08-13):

Investigate replacing the e-fuse with a toshiba part

mmroden, 2022-08-13:
Efuses are hard to find, we need a replacement part.  This ticket is an investigation for whether this part can replace the existing efuse.

https://www.digikey.co.uk/en/products/detail/toshiba-semiconductor-and-storage/TCKE800NL-RF/12324957

mechatroniks-git, 2022-08-15:
Quick comparison of features:

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

##TLDR:

### Toshiba
- Toshiba part will be easier to solder and should have less components required
- Toshiba requires external MOSFET for reverse polarity protection

### TI
- TI part is cheaper and more featured
- TI has adjustable Overvoltage, Toshiba has a fixed value @ 15.1V
- TI has slightly lower on-resistance (less heat) - but still good
- TI has status outputs
- TI has better nuisance tripping resilience

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

mechatroniks-git, 2022-08-15:
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

https://octopart.com/tcke812na%2Crf-toshiba-109207110?r=sp
vs
https://octopart.com/tps259472arpwr-texas+instruments-113046828?r=sp

mechatroniks-git, 2022-08-15:
TI circuit:

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

Toshiba Circuit:
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

darraghbr, 2022-08-19:
Just a couple of quick agenda items for the meeting.

- What is the stock like for the transient suppression diodes and the external FET
- Do we currently take advantage of the reverse polarity protection on the current board rev (I seem to recall that we do) and do we think that it is necessary to keep that functionality (I think it is)

mechatroniks-git, 2022-08-19:
Reverse polarity is a good thing, certainly worth the $.31 per board.

These are the recommended parts, all made by Toshiba. Cost at 100 board qty.  Lots of stock at the moment.
TVS: Lots of stock, $0.20/board [octopart](https://octopart.com/df2s23p2ctc%2Cl3f-toshiba-87695657?r=sp)
SBD: Lots of stock, $0.22/board [octopart](https://octopart.com/cuhs20s30%2Ch3f-toshiba-97210178?r=sp)
FET: Lots of stock, $0.31/board [octopart](https://octopart.com/ssm6k513nu%2Clf-toshiba-75194178?r=sp)

darraghbr, 2022-08-20:
https://www.digikey.co.uk/en/products/detail/toshiba-semiconductor-and-storage/TCKE812NA-RF/12324959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

Updated digikey link for the correct over voltage and stock

mechatroniks-git, 2022-12-22:
With Texas Instruments showing stock, request was made to order 250 parts for stock to avoid having to design in the Toshiba part.

Closing this issue for the time being.

Closed 2022-12-22.

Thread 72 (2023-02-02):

Add tooling holes for DFM

mechatroniks-git, 2023-02-02:
Add 3 x 1.05mm holes on pcb, see https://cybercitycircuits.com/2023/01/12/placing-an-assembly-order-with-cyber-city-circuits/

Closed 2025-01-31.

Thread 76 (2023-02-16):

Create through-hole board design for hand soldering kit

mechatroniks-git, 2023-02-16:
Create a new design using only through hole parts, easily available from maker sources (Adafruit, SparkFun, Amazon, etc.)

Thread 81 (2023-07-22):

Validate V2 of the through-hole board design

mmroden, 2023-07-22:
v2 of the through-hole board design contains updated blower FET circuitry in case Sean's v1 assembly was correct but still released smoke.  This board design needs to be validated by running a fan for some time without releasing smoke.

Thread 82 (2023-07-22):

Validate v1 of the through-hole board design

mmroden, 2023-07-22:
The through-hole board design needs to be validated, meaning making sure that it runs for a while without releasing the magic smoke.

tbd Monday July 24th 8am PST/11am EST.

mmroden, 2023-07-24:
Mark Porter sees this after flashing his chip:

```
Pot:270,PWM:85,BatRaw:1943,Batt:3879
Pot:372,PWM:99,BatRaw:3869,Batt:3878
Pot:338,PWM:91,BatRaw:3707,Batt:3860
Pot:370,PWM:98,BatRaw:3513,Batt:3825
Pot:375,PWM:100,BatRaw:3639,Batt:3806
ESP-ROM:esp32c3-api1-20210207
Starting up
PAPRA TH 03JUNE2023
PCB v1
ESP32C3 PROCESSOR
CUI BLOWER 154
Tetra Bio Distributed
```

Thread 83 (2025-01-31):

Update through hole board designs

mmroden, 2025-01-31:
The throughholes need:

QR code to point to https://tetrabiodistributed.github.io for assembly instructions
If room, QR code for https://tetrab.io

Resistor value updates
Cathode/Anode LED markings need to be a little bit clearer

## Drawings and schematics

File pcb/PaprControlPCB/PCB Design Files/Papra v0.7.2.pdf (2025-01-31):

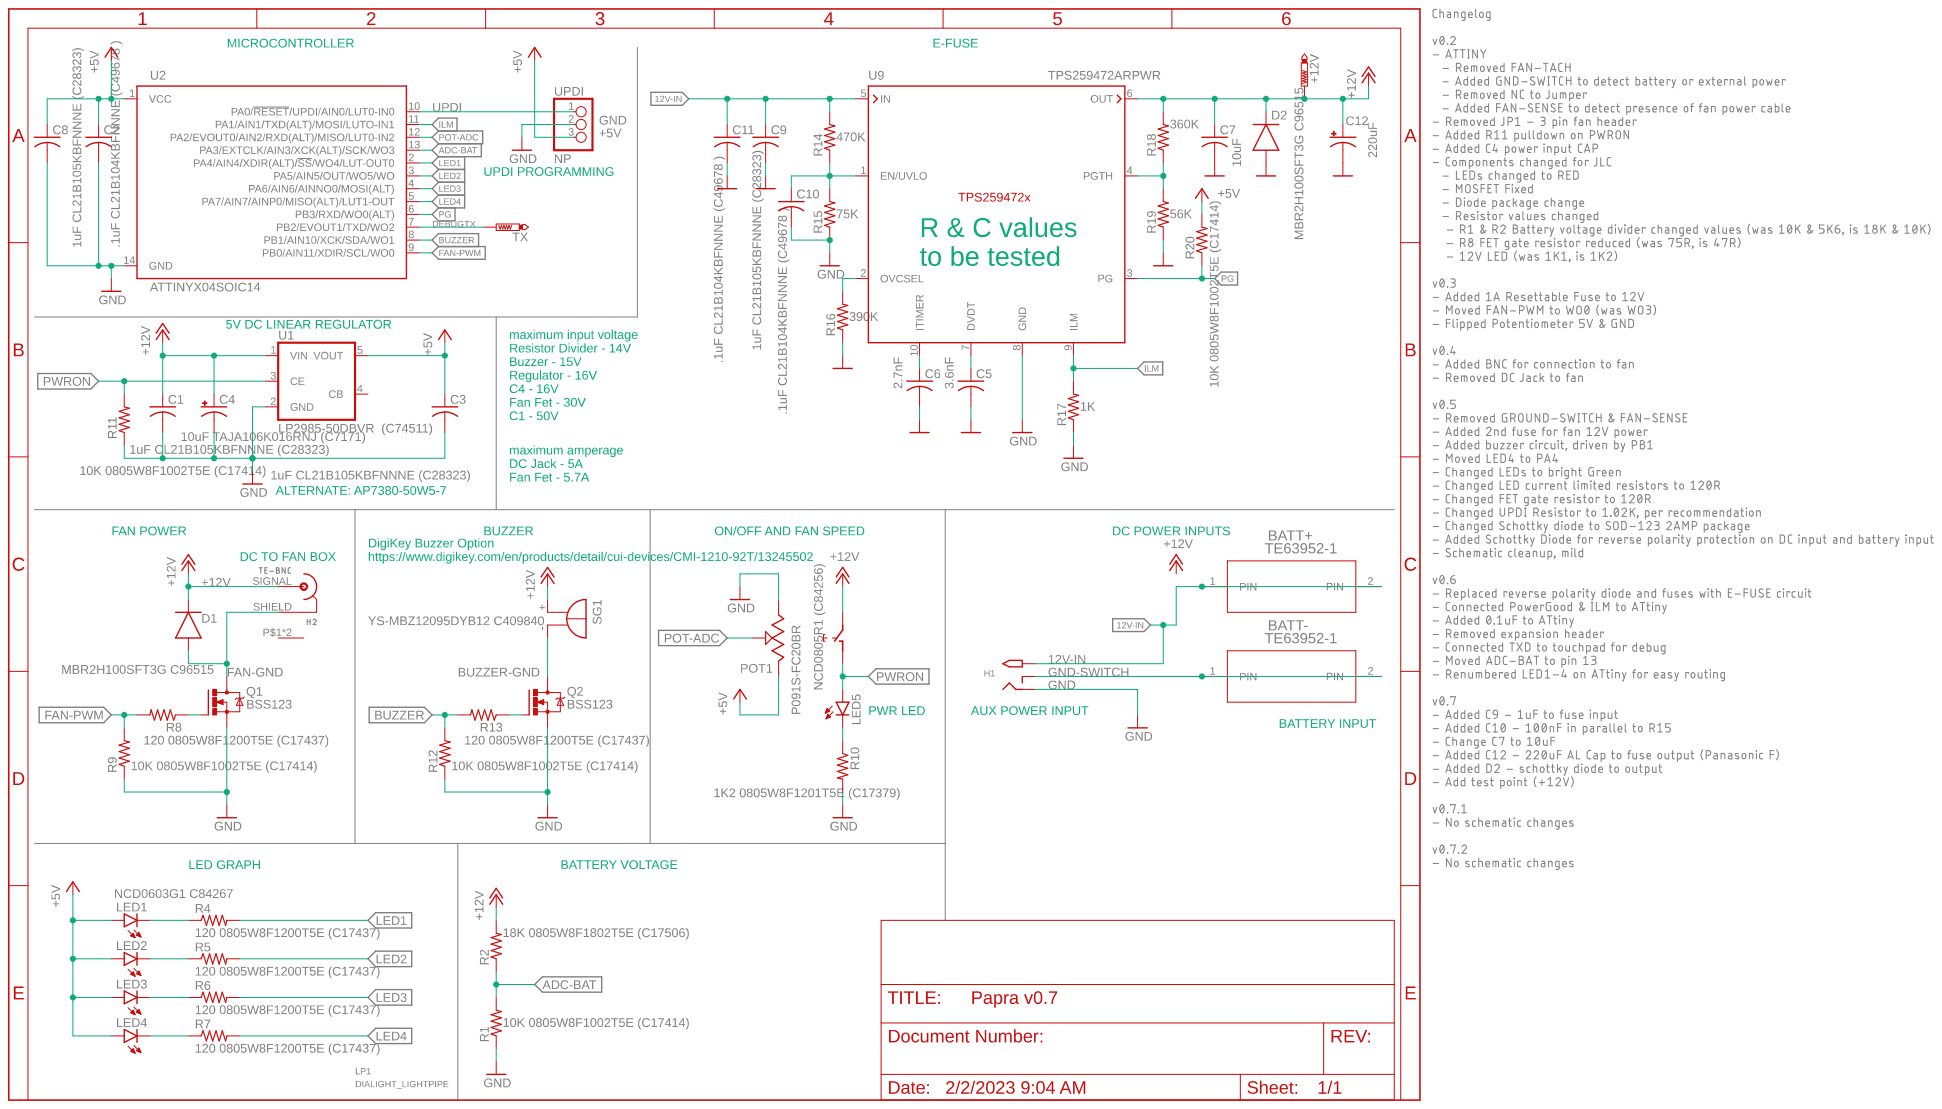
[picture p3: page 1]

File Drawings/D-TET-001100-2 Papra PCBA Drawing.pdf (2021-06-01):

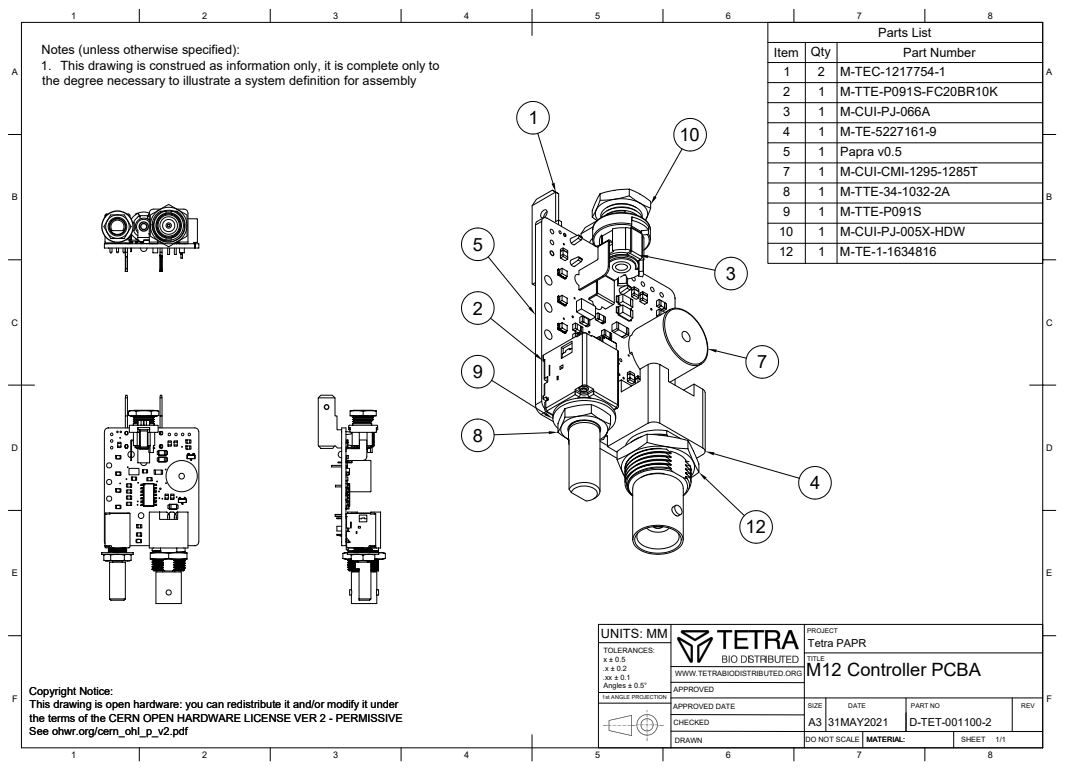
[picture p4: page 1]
8 BCDEF; ABCDEF Copyright Notice: This drawing is open hardware: you can redistribute it and/or modify it under the terms of the CERN OPEN HARDWARE LICENSE VER 2 - PERMISSIVE See ohwr.org/cern_ohl_p_v2.pdf; Parts List Item; Qty; Part Number 1; M-TEC-1217754-1 2; M-TTE-P091S-FC20BR10K 3; M-CUI-PJ-066A 4; Papra v0.5 7; M-CUI-CMI-1295-1285T 8; M-TTE-34-1032-2A 9; M-TTE-P091S 10; M-CUI-PJ-005X-HDW 12; M-TE-1-1634816 PROJECT TITLE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

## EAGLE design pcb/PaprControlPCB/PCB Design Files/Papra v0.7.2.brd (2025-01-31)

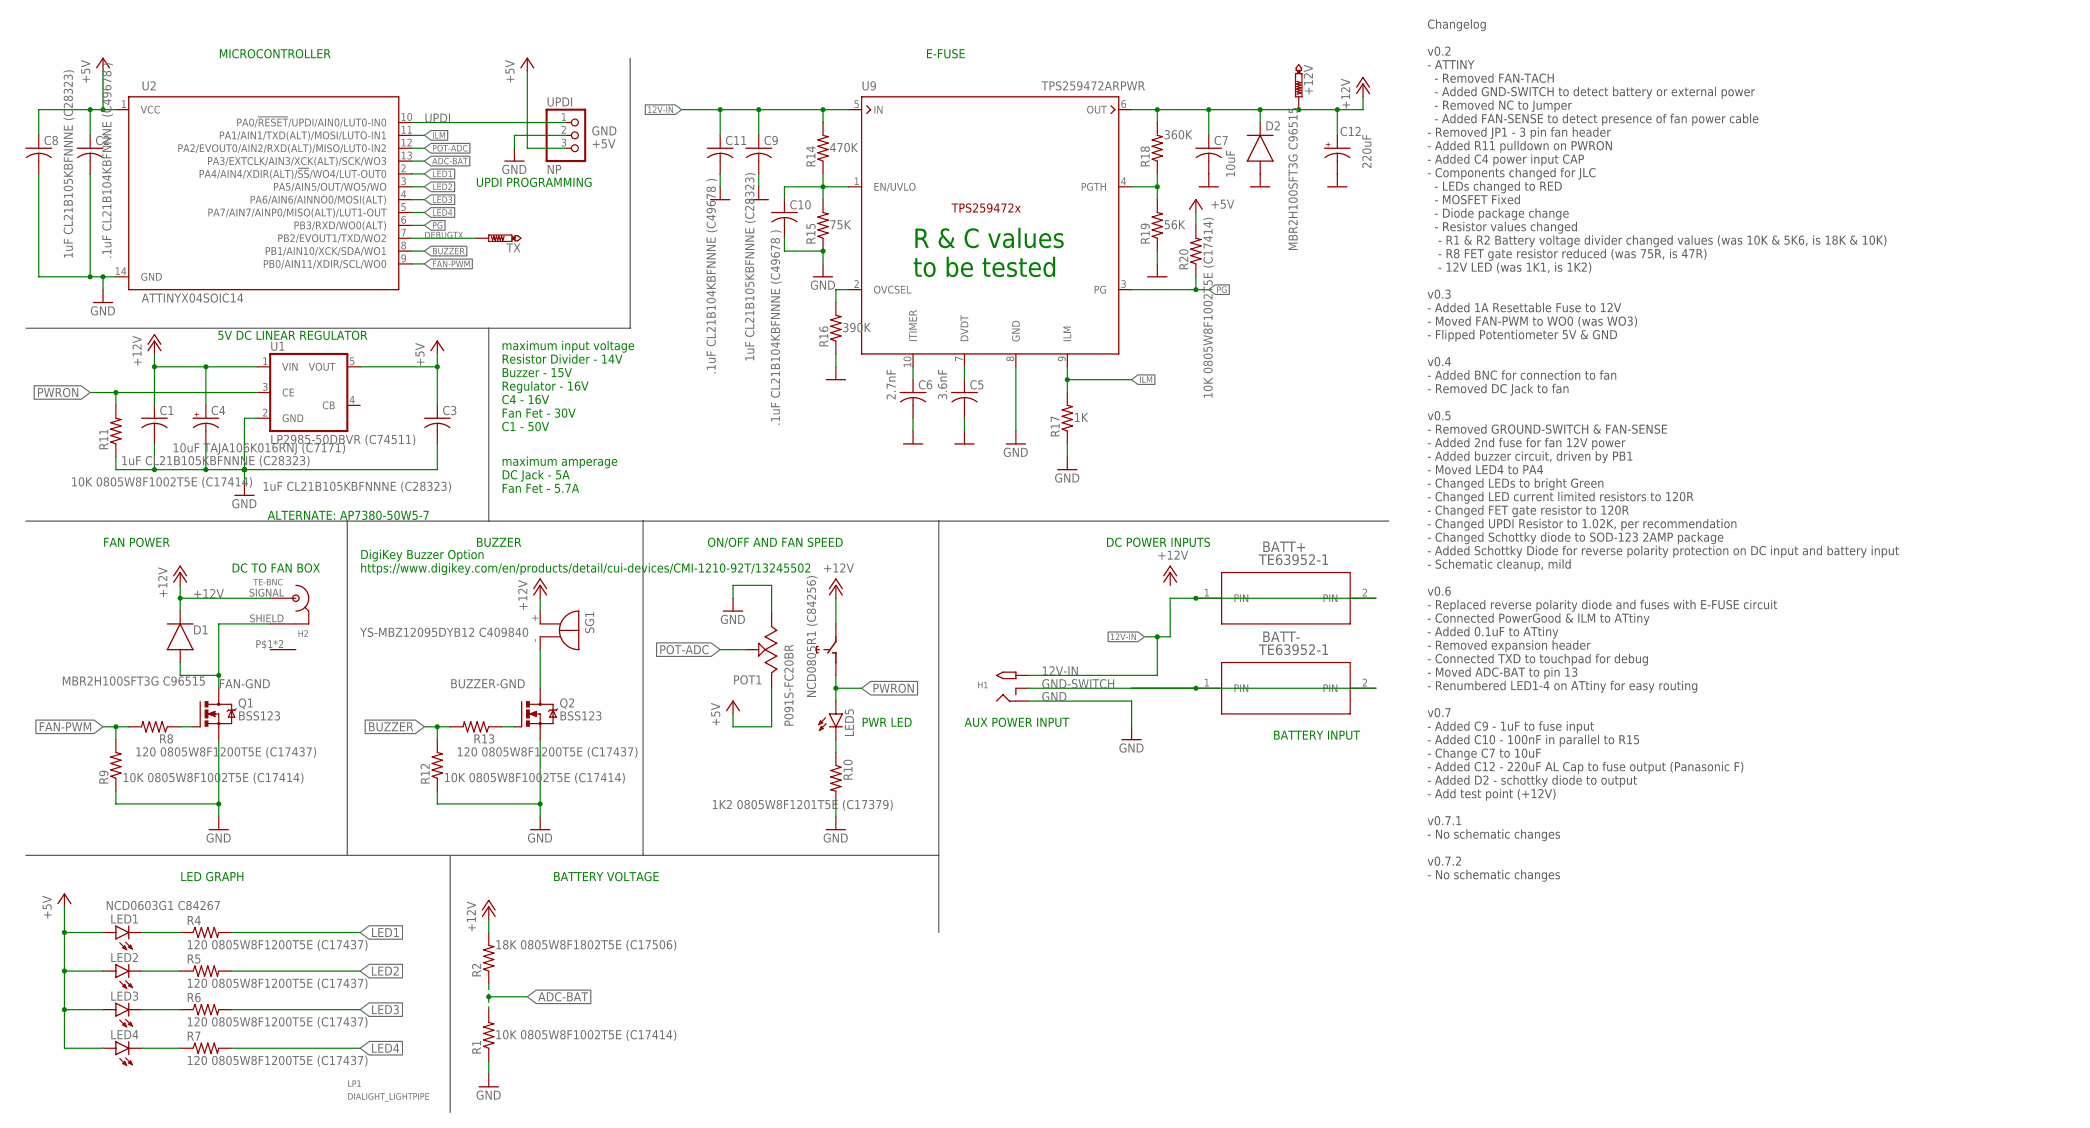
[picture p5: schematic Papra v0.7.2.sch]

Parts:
+12V: PTR1B1,27; B1,27
BATT+: TE63952-1
BATT-: TE63952-1
C1, C3, C8, C11: 1uF CL21B105KBFNNNE (C28323); C0805
C2, C9, C10: .1uF CL21B104KBFNNNE (C49678 ); C0805
C4: 10uF TAJA106K016RNJ (C7171); A/3216-18R
C5: 3.6nF; C0805
C6: 2.7nF; C0805
C7: 10uF; C0805
C12: 220uF; PANASONIC_F
D1, D2: MBR2H100SFT3G C96515; SODFL3718X115
H1: M-CUI-PJ-066A; DCJACK-PJ-066A
H2: TE-BNC
LED1, LED2, LED3, LED4: NCD0603G1 C84267; CHIPLED_0805
LED5: NCD0805R1 (C84256); CHIPLED_0805
LP1: DIALIGHT_LIGHTPIPE; DIALIGHT_5151020F_/LEDS
POT1: P091S-FC20BR
Q1, Q2: BSS123; SOT23
R1, R9, R11, R12, R20: 10K 0805W8F1002T5E (C17414); R0805
R2: 18K 0805W8F1802T5E (C17506); R0805
R4, R5, R6, R7, R8, R13: 120 0805W8F1200T5E (C17437); R0805
R10: 1K2 0805W8F1201T5E (C17379); R0805
R14: 470K; R0805
R15: 75K; R0805
R16: 390K; R0805
R17: 1K; R0805
R18: 360K; R0805
R19: 56K; R0805
SG1: YS-MBZ12095DYB12 C409840; F/TMB
TX: PTR1PAD1-13; P1-13
U1: LP2985-50DBVR (C74511); SOT25
U2: ATTINYX04SOIC14; SOIC127P600X144-14
U9: TPS259472ARPWR; QFN45P200X200X100-16N
UPDI: NP; 1X03

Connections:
12V-IN: BATT+.1, BATT+.2, C9.1, C11.1, H1.PWR (TIP), R14.2, U9.5 (IN)
+5V: C2.1, C3.1, C8.1, LED1.A, LED2.A, LED3.A, LED4.A, POT1.3, R20.2, U1.5 (VOUT), U2.1 (VCC), UPDI.3
+12V: +12V.TP, C1.1, C4.+, C7.1, C12.+, D1.1 (C), D2.1 (C), H2.SIGNAL (P1), POT1.NO (5), R2.2, R18.2, SG1.+, U1.1 (VIN), U9.6 (OUT)
ADC-BAT: R1.2, R2.1, U2.13 (PA3/EXTCLK/AIN3/XCK(ALT)/SCK/WO3)
BUZZER: R12.2, R13.2, U2.8 (PB1/AIN10/XCK/SDA/WO1)
BUZZER-GND: Q2.3 (D), SG1.-
DEBUGTX: TX.TP, U2.7 (PB2/EVOUT1/TXD/WO2)
DVDT: C5.1, U9.7 (DVDT)
EN/UVLO: C10.1, R14.1, R15.2, U9.1 (EN/UVLO)
FAN-GND: D1.2 (A), H2.SHIELD (P2), Q1.3 (D)
FAN-PWM: R8.2, R9.2, U2.9 (PB0/AIN11/XDIR/SCL/WO0)
FETGATE: Q1.1 (G), R8.1
FETGATE1: Q2.1 (G), R13.1
GND: C1.2, C2.2, C3.2, C4.-, C5.2, C6.2, C7.2, C8.2, C9.2, C10.2, C11.2, C12.-, D2.2 (A), H1.GND (RING), POT1.1, Q1.2 (S), Q2.2 (S), R1.1, R9.1, R10.2, R11.1, R12.1, R15.1, R16.1, R17.1, R19.1, U1.2 (GND), U2.14 (GND), U9.8 (GND), UPDI.2
GND-SWITCH: BATT-.1, BATT-.2, H1.GNDBREAK (RING_SW)
ILM: R17.2, U2.11 (PA1/AIN1/TXD(ALT)/MOSI/LUTO-IN1), U9.9 (ILM)
ITIMER: C6.1, U9.10 (ITIMER)
LED1: R4.2, U2.2 (PA4/AIN4/XDIR(ALT)/!SS!/WO4/LUT-OUT0)
LED1-R: LED1.C, R4.1
LED2: R5.2, U2.3 (PA5/AIN5/OUT/WO5/WO)
LED2-R: LED2.C, R5.1
LED3: R6.2, U2.4 (PA6/AIN6/AINNO0/MOSI(ALT))
LED3-R: LED3.C, R6.1
LED4: R7.2, U2.5 (PA7/AIN7/AINP0/MISO(ALT)/LUT1-OUT)
LED4-R: LED4.C, R7.1
LED5-R: LED5.C, R10.1
OVCSEL: R16.2, U9.2 (OVCSEL)
PG: R20.1, U2.6 (PB3/RXD/WO0(ALT)), U9.3 (PG)
PGTH: R18.1, R19.2, U9.4 (PGTH)
POT-ADC: POT1.2, U2.12 (PA2/EVOUT0/AIN2/RXD(ALT)/MISO/LUT0-IN2)
PWRON: LED5.A, POT1.COM (4), R11.2, U1.3 (CE)
UPDI: U2.10 (PA0/!RESET!/UPDI/AIN0/LUT0-IN0), UPDI.1

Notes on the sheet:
AUX POWER INPUT
BATTERY INPUT
E-FUSE
5V DC LINEAR REGULATOR
ON/OFF AND FAN SPEED
FAN POWER
MICROCONTROLLER
LED GRAPH
BATTERY VOLTAGE
DC TO FAN BOX
UPDI PROGRAMMING
PWR LED
ALTERNATE: AP7380-50W5-7
Changelog v0.2 - ATTINY - Removed FAN-TACH - Added GND-SWITCH to detect battery or external power - Removed NC to Jumper - Added FAN-SENSE to detect presence of fan power cable - Removed JP1 - 3 pin fan header - Added R11 pulldown on PWRON - Added C4 power input CAP - Components changed for JLC - L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
BUZZER
maximum input voltage Resistor Divider - 14V Buzzer - 15V Regulator - 16V C4 - 16V Fan Fet - 30V C1 - 50V
maximum amperage DC Jack - 5A Fan Fet - 5.7A
DigiKey Buzzer Option https://www.digikey.com/en/products/detail/cui-devices/CMI-1210-92T/13245502
DC POWER INPUTS
R & C values to be tested

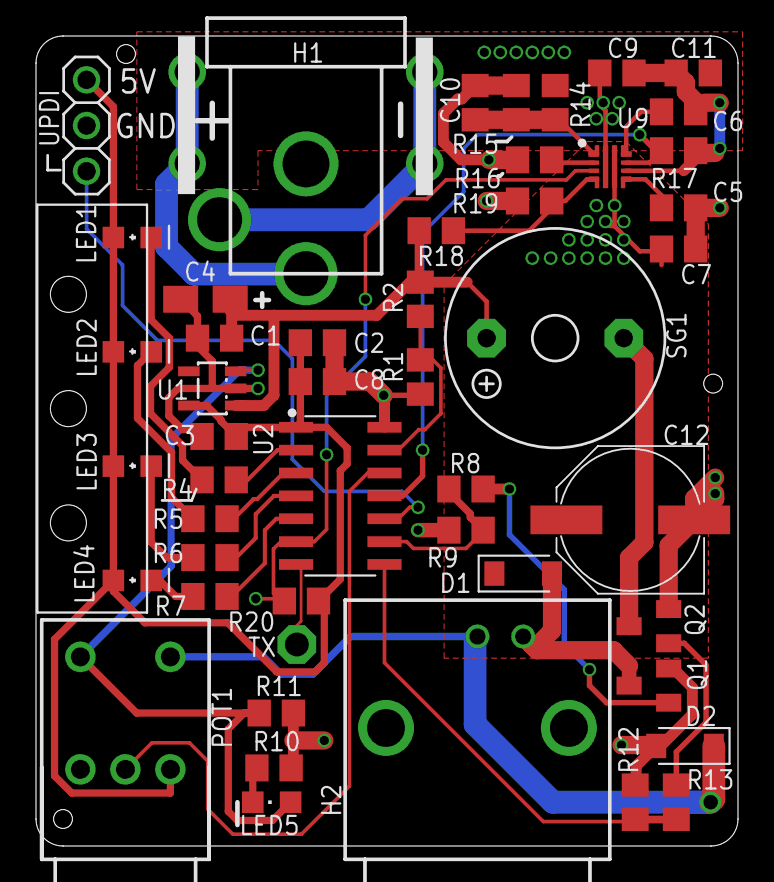
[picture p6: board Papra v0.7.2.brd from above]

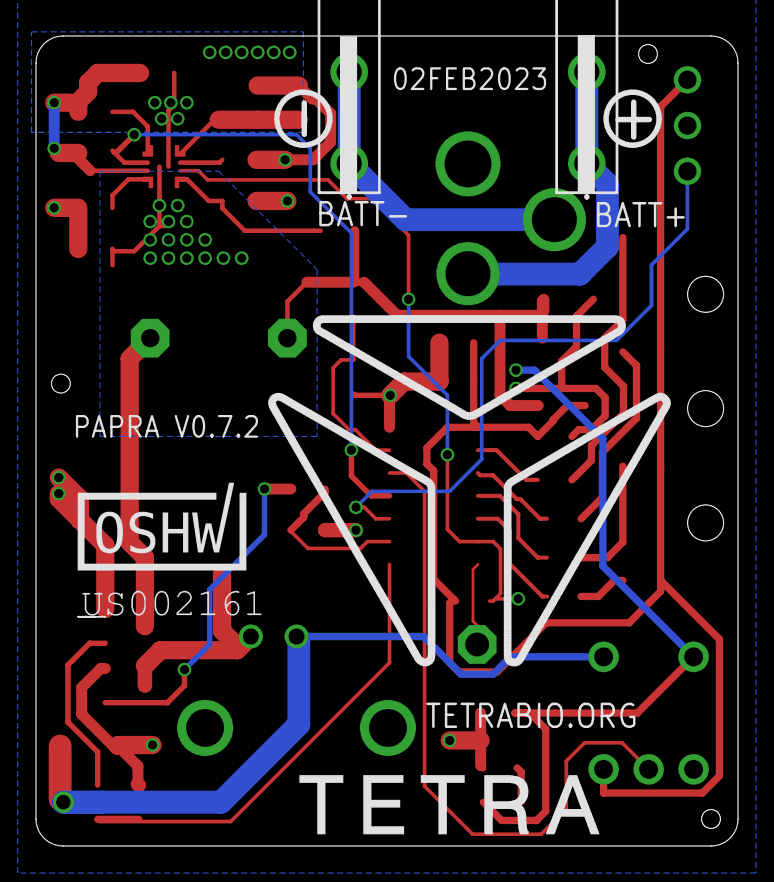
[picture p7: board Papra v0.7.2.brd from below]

Board: 2 copper layers, 39.0 x 45.0 mm, 53 parts (3 on the bottom side), 32 nets.

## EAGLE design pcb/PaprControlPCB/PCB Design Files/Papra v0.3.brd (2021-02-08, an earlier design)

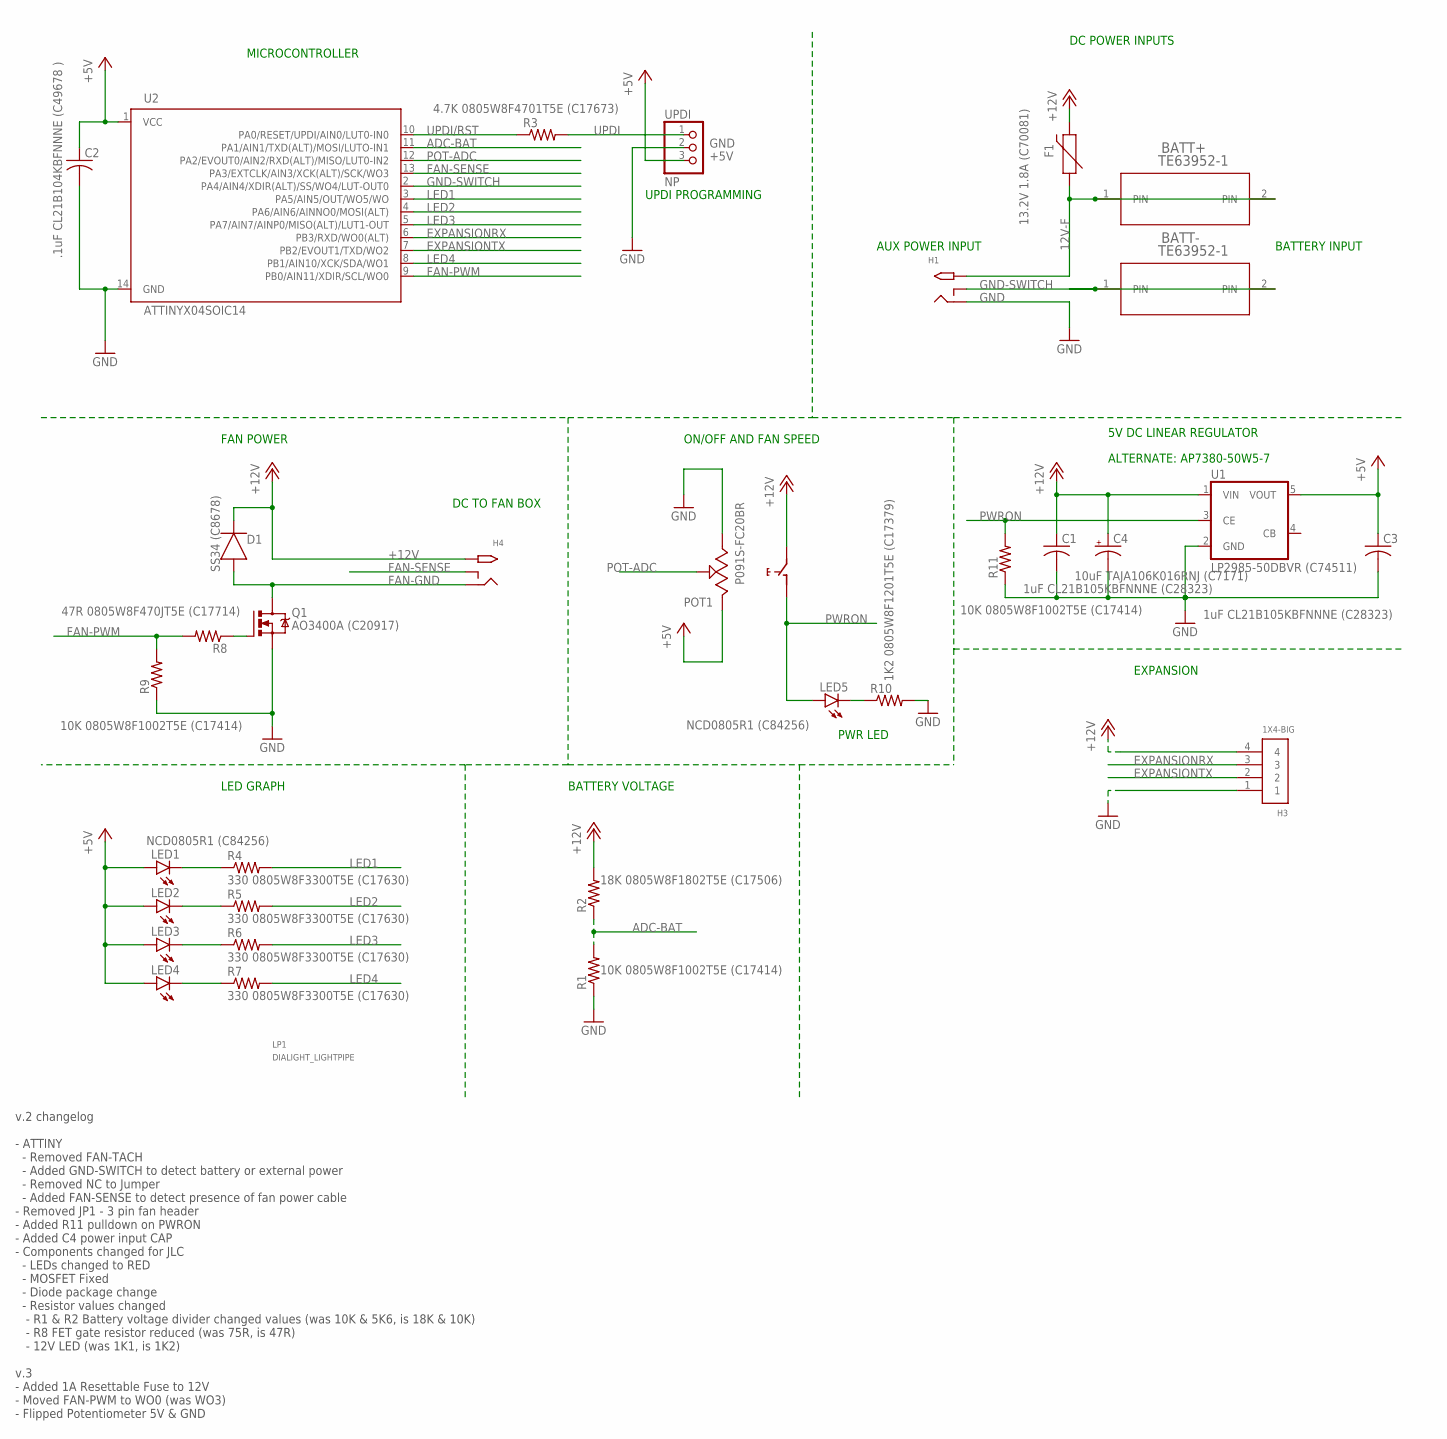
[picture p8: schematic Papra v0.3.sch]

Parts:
BATT+: TE63952-1
BATT-: TE63952-1
C1, C3: 1uF CL21B105KBFNNNE (C28323); C0805
C2: .1uF CL21B104KBFNNNE (C49678 ); C0805
C4: 10uF TAJA106K016RNJ (C7171); A/3216-18R
D1: SS34 (C8678); DIOM5226X290N
F1: 13.2V 1.8A (C70081); 1206
H1, H4: M-CUI-PJ-066A; DCJACK-PJ-066A
H3: 1X4-BIG; 1X04-BIG
LED1, LED2, LED3, LED4, LED5: NCD0805R1 (C84256); CHIPLED_0805
LP1: DIALIGHT_LIGHTPIPE; DIALIGHT_5151020F_/LEDS
POT1: P091S-FC20BR
Q1: AO3400A (C20917); SOT23
R1, R9, R11: 10K 0805W8F1002T5E (C17414); R0805
R2: 18K 0805W8F1802T5E (C17506); R0805
R3: 4.7K 0805W8F4701T5E (C17673); R0805
R4, R5, R6, R7: 330 0805W8F3300T5E (C17630); R0805
R8: 47R 0805W8F470JT5E (C17714); R0805
R10: 1K2 0805W8F1201T5E (C17379); R0805
U1: LP2985-50DBVR (C74511); SOT25
U2: ATTINYX04SOIC14; SOIC127P600X144-14
UPDI: NP; 1X03

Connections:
12V-F: BATT+.1, BATT+.2, F1.1, H1.PWR (TIP)
+5V: C2.1, C3.1, LED1.A, LED2.A, LED3.A, LED4.A, POT1.3, U1.5 (VOUT), U2.1 (VCC), UPDI.3
+12V: C1.1, C4.+, D1.1 (C), F1.2, H3.4, H4.PWR (TIP), POT1.NO (5), R2.2, U1.1 (VIN)
ADC-BAT: R1.2, R2.1, U2.11 (PA1/AIN1/TXD(ALT)/MOSI/LUTO-IN1)
EXPANSIONRX: H3.3, U2.6 (PB3/RXD/WO0(ALT))
EXPANSIONTX: H3.2, U2.7 (PB2/EVOUT1/TXD/WO2)
FAN-GND: D1.2 (A), H4.GND (RING), Q1.3 (D)
FAN-PWM: R8.2, R9.2, U2.9 (PB0/AIN11/XDIR/SCL/WO0)
FAN-SENSE: H4.GNDBREAK (RING_SW), U2.13 (PA3/EXTCLK/AIN3/XCK(ALT)/SCK/WO3)
FETGATE: Q1.1 (G), R8.1
GND: C1.2, C2.2, C3.2, C4.-, H1.GND (RING), H3.1, POT1.1, Q1.2 (S), R1.1, R9.1, R10.2, R11.1, U1.2 (GND), U2.14 (GND), UPDI.2
GND-SWITCH: BATT-.1, BATT-.2, H1.GNDBREAK (RING_SW), U2.2 (PA4/AIN4/XDIR(ALT)/SS/WO4/LUT-OUT0)
LED1: R4.2, U2.3 (PA5/AIN5/OUT/WO5/WO)
LED1-R: LED1.C, R4.1
LED2: R5.2, U2.4 (PA6/AIN6/AINNO0/MOSI(ALT))
LED2-R: LED2.C, R5.1
LED3: R6.2, U2.5 (PA7/AIN7/AINP0/MISO(ALT)/LUT1-OUT)
LED3-R: LED3.C, R6.1
LED4: R7.2, U2.8 (PB1/AIN10/XCK/SDA/WO1)
LED4-R: LED4.C, R7.1
LED5-R: LED5.C, R10.1
POT-ADC: POT1.2, U2.12 (PA2/EVOUT0/AIN2/RXD(ALT)/MISO/LUT0-IN2)
PWRON: LED5.A, POT1.COM (4), R11.2, U1.3 (CE)
UPDI: R3.2, UPDI.1
UPDI/RST: R3.1, U2.10 (PA0/RESET/UPDI/AIN0/LUT0-IN0)

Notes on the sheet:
AUX POWER INPUT
BATTERY INPUT
DC POWER INPUTS
5V DC LINEAR REGULATOR
ON/OFF AND FAN SPEED
FAN POWER
MICROCONTROLLER
LED GRAPH
BATTERY VOLTAGE
EXPANSION
DC TO FAN BOX
UPDI PROGRAMMING
PWR LED
ALTERNATE: AP7380-50W5-7
v.2 changelog - ATTINY - Removed FAN-TACH - Added GND-SWITCH to detect battery or external power - Removed NC to Jumper - Added FAN-SENSE to detect presence of fan power cable - Removed JP1 - 3 pin fan header - Added R11 pulldown on PWRON - Added C4 power input CAP - Components changed for JLC - LE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

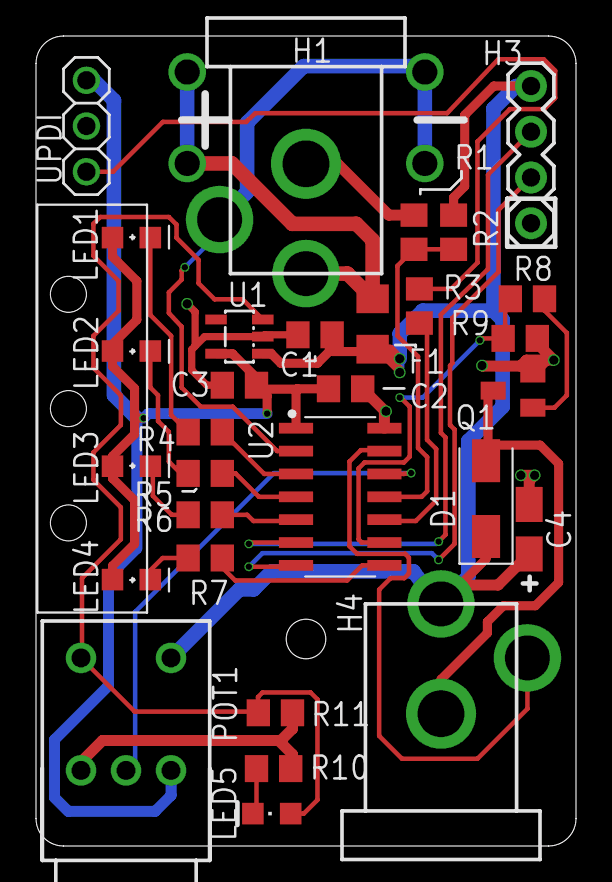
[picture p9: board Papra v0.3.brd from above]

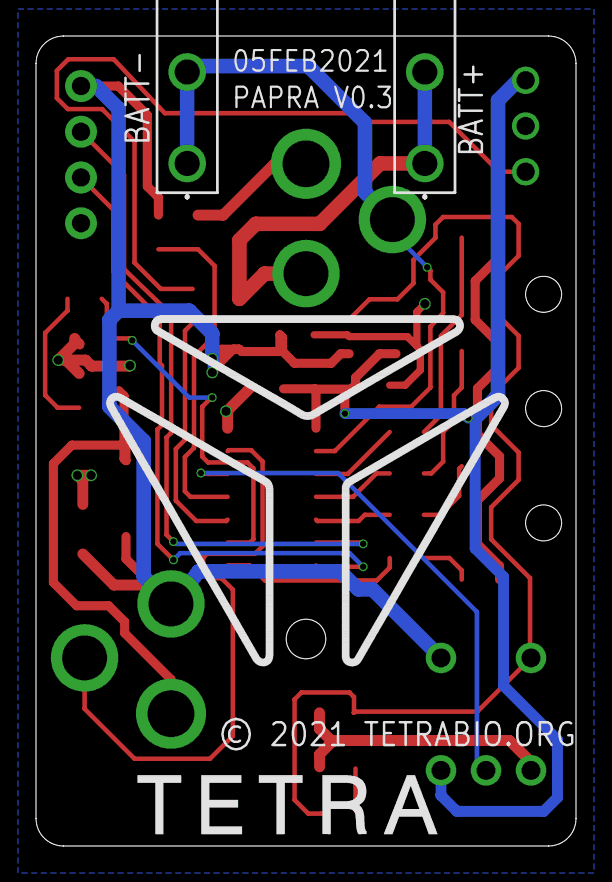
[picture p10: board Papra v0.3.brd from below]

Board: 2 copper layers, 30.0 x 45.0 mm, 33 parts (2 on the bottom side), 25 nets.

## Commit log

2020-11-24 Added fuel gauge LED code
2020-11-25 Added state machine for LEDs
2020-11-26 Implemented in PWM to prevent motor stalling at low end
2020-11-28 Added battery smoothing, fixed scaling formula. Tested
2020-12-11 PCB v0.2
    [Papra v0.10.brd, Papra v0.10.sch, Papra v0.20.brd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]
2020-12-11 Adding pdf schematic
2021-01-09 v0.2 PCB updates and knob speed reverse
2021-01-10 Switching to AtTiny1604 for codespace headroom
2021-01-11 Papra PCB Ready for release
    [PaprControl v0.2 BOM JLCPCB.xlsx, PaprControl v0.2 nonJLC BOM.csv, PaprControl v0.20.brd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]
2021-01-15 Updating the boards for the 3rd build
    [Papra v0.3.brd, Papra v0.3.sch]
2021-01-19 Updates/Fixes to PCB and PCBA files.
    Added TETRA logo to bottom silk
    [PaprControl v0.3 BOM JLCPCB.xlsx, PaprControl v0.3 nonJLC BOM.csv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]
2021-01-19 design files
    [Papra v0.3.brd, Papra v0.3.sch]
2021-01-21 Added 1A resettable fuse to 12V power
    [PaprControl v0.3 BOM JLCPCB.xlsx, Papra v0.3.brd, Papra v0.3.sch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]
2021-01-28 20kHz PWM freq (need to test)
2021-02-01 20kHz PWM with re-calibrated minimum PWM value
2021-02-05 v0.3 release candidate
    [Papra v0.3.brd, Papra v0.3.sch]
2021-02-06 Reverting back to v0.2
    [Papr v0.2 BOM JLCPCB.xlsx, PaprControl v0.20.brd, PaprControl v0.20.sch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]
2021-02-07 v0.3 pcb
    [Papr v0.2 BOM JLCPCB.xlsx, PaprControl v0.3 BOM JLCPCB.xlsx, PaprControl v0.3 nonJLC BOM.csv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]
2021-02-15 Updated fan box PCB to v0.3 (IP68 DC Jack)
    [Papra Fan Box PCBA v0.3.step, PapraFanBox_v0.1 BOM.csv, PapraFanBox_v0.1 PCBA.step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]
2021-02-22 STEP file update
    [Papra Fan Box PCBA v0.3.step]
2021-02-22 Adding in drawings for the PCBA
2021-02-26 fixing pin# mistake in code comments
2021-03-10 Update README.md
    Update with new arduino config
2021-03-24 v.4 board files, released batch of 3 to OSH
    [Papra v0.4.brd, Papra v0.4.sch]
2021-04-24 PAPRA Control PCB v0.4 design and manufacturing
    3 Boards have been made (Oshpark), just pushing the documentation as v0.5 is imminent.
    Consider v0.4 a test version
    [PaprControl v0.3 BOM JLCPCB.xlsx, PaprControl v0.3 nonJLC BOM.csv, PaprControl v0.4 BOM.csv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]
2021-04-24 Remove fan box board files and update firmware
    Fan box no longer has PCB
    Firmware needs to run for v.3 or later
    [Papra Fan Box PCBA v0.3.step, PapraFanBox_v0.3 BOM.csv, PapraFanBox_v0.3.brd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]
2021-05-13 firmware for v0.3 PCB
2021-05-13 Updating readme
    Added note about commenting out the LED startup sequence to fit in a 2K flash code space
2021-05-16 Updating PCBA Drawing
2021-05-24 V.5 Release candidate
    [PaprControl v0.4 BOM.csv, PaprControl v0.5 Complete BOM.csv, Papra Control PCBA v0.5.step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]
2021-07-27 Board ready for review
    Closes #53
    [PaprControl v0.5 Complete BOM.csv, Papra Control PCBA v0.5.step, Papra v0.5_top_bom.csv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]
2021-07-28 Updates based on feedback
    [PaprControl v0.5 Complete BOM.csv, Papra v0.6.brd, Papra v0.6.sch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]
2021-09-06 Adding gerbers
2022-05-16 Updating to v0.7
    Closes #59
    [PaprControl v0.5 Complete BOM.csv, Papra v0.6_top_bom.csv, Papra v0.7.brd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]
2022-05-27 Updated changelogs for schematic & PCB
    [Papra v0.7.brd, Papra v0.7.sch]
2023-02-02 DFM Update
    Closes #72
    Closes #73
    Closes #74
    [Cyber City PAPRA V0.7 BOM.xlsx, Papra v0.7.2.brd, Papra v0.7.2.sch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]

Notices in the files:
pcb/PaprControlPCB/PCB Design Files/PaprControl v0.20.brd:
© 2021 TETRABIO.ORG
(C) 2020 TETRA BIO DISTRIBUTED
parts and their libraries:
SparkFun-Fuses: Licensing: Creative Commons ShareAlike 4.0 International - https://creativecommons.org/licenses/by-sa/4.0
